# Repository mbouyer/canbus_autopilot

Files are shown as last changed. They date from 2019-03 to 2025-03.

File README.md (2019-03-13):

# canbus_autopilot
this is a canbus-connected marine autopilot, composed of 3 main parts:
* an IMU, implementing a MARG algorithm and transmitting attitude and rate of turn PGNs
* a display unit, allowing the user to display and change parameters of the autopilot
* a command unit, which is the autopilot itself. It drives the rudder's motor (in my case, and old Autohelm 2000 tiller).

These parts are built around a pic18f26j50, for its low power and native can support. The CAN protocol is based on J1939 and reuses NMEA2000 PGNs when possible.

There is also wxpilot, a wxwidget/socketcan utility which allows to show and change some of the autopilot's parameters from a unix computer (see my marine_charplotter repository)

The display unit can also decode and display navigation PGNs sent by my nmea2000_pi OpenCPN plugin.

I use this hardware for sailing since several years now

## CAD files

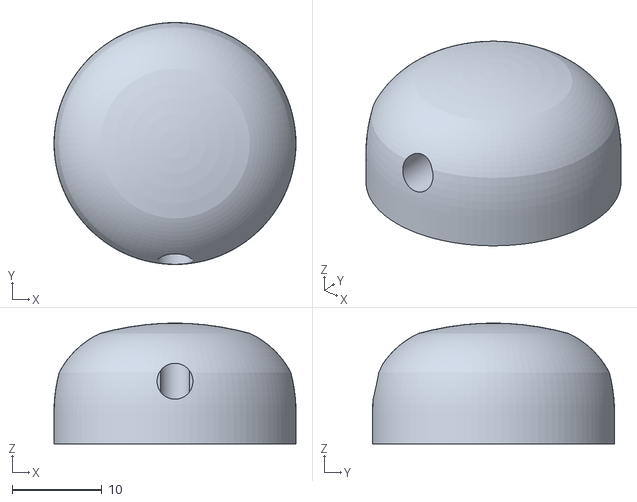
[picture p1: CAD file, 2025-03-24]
hardware/cad/bouton-3mm.stl
27.0 x 27.0 x 13.5

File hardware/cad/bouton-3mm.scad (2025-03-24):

$fa = 6;
$fs = 0.5;
$fn = 100;

difference() {
    rotate_extrude(angle = 360, convexity = 100) {
	import("bouton-3mm.dxf");
    };
    translate([0,0,7]) rotate([90,0,0]) cylinder(d=4, h=15);
}

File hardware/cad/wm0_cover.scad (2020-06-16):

$fn = 100;
// ABS: environ 1mm de retrait
// longueur_b = 4.10 * 25.4;
longueur_b = 113.8 + 0.9;
// largeur_b = 2.60 * 25.4;
largeur_b = 83.5 + 0.9;
hauteur_b = 60;
hauteur_b_droite = 7;
angle=4.9;
conge=4;
base_ep = 2;
murs_ep = 1.5;

hole_l = 22;
hole_x = 18;
hole_z = 24;

module hole() {
	translate([-murs_ep*2, 0, 0]) rotate([0,90,0]) union () {
		cylinder(d = hole_l, h=murs_ep * 4, $fn = 500);
		translate([0, -hole_l/2, 0]) cube([hole_z, hole_l, murs_ep * 4]);
	};
}

module coupe_conge(r) {
	translate([-(r - r * sin(angle)), -r, 0]) difference() {
		polygon(points = [
		    [0, 0],
		    [0, r],
		    [(r - r * sin(angle)), r],
		    [r, 0]
		    ]);
		circle(r = r, $fn = 500);
	};
}

module trapeze_conge(longueur, hauteur, r) {
	difference() {
	    polygon(points = [
		[-longueur/2, 0],
		[-(longueur/2 - hauteur * sin(angle)), hauteur],
		[(longueur/2 - hauteur * sin(angle)), hauteur],
		[longueur/2, 0]
		]);
	    translate([-(longueur/2 - hauteur * sin(angle)), hauteur, 0])
		rotate([0,180,0]) coupe_conge(r = r);
	    translate([(longueur/2 - hauteur * sin(angle)), hauteur, 0])
		coupe_conge(r = r);
	};
}

module pyramidal_1(longueur, largeur, hauteur, r) {
	rotate([90,0,0]) linear_extrude(height=largeur, center=true, convexity=10, twist=0)
	    trapeze_conge(longueur=longueur, hauteur=hauteur, r = r);
}

module pyramidal(longueur, largeur, hauteur, r) {
	intersection() {
		pyramidal_1(longueur, largeur, hauteur, r);
		rotate([0,0,90]) pyramidal_1(largeur, longueur, hauteur, r);
	}
}

module base(longueur, largeur, hauteur, r) {
	union() {
		translate([0,0,hauteur_b_droite / 2]) cube([longueur, largeur, hauteur_b_droite], center = true);
		translate([0,0,hauteur_b_droite]) pyramidal(longueur, largeur, hauteur_b - hauteur_b_droite, r);
	}
}
	

module box() {
	rotate([180,0,0]) difference() {
		translate([0,0,base_ep]) base(longueur_b+murs_ep*2, largeur_b+murs_ep*2, hauteur_b+base_ep, 0);
		base(longueur_b, largeur_b, hauteur_b, 4);
		translate([longueur_b/2, -largeur_b/2+hole_x, hole_z]) hole();
	};
}

box();

// difference() {
//  	box();
//  	translate([0,0,-hauteur_b / 2 - 20]) cube([longueur_b+10, largeur_b+10, hauteur_b], center=true);
// };
// hole();

// projection(cut=true) translate([0,0, -0.1]) box();

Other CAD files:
hardware/cad/bouton-3mm.dxf

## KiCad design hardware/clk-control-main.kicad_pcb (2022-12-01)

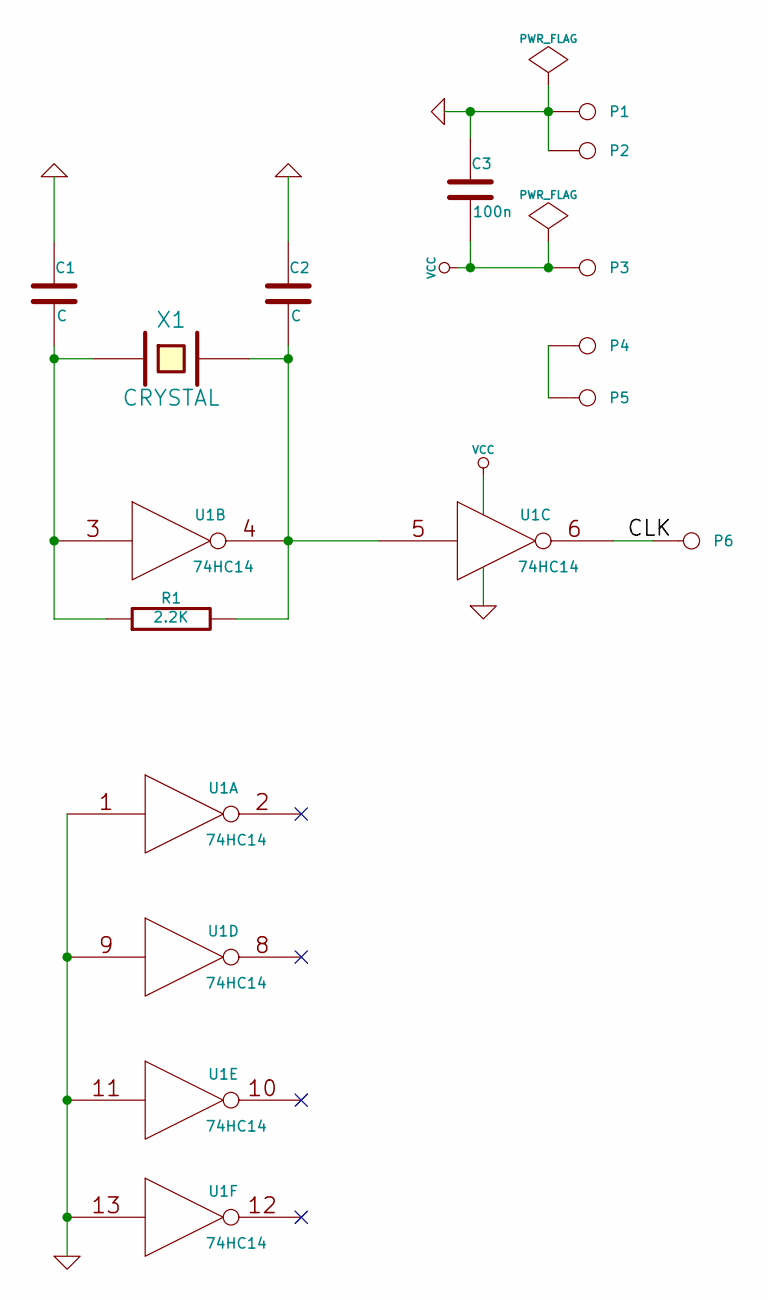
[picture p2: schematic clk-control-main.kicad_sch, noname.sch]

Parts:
C1, C2: C
C3: 100n
P1, P2, P3, P4, P5, P6: CONN_1
R1: 2.2K
U1: 74HC14
X1: CRYSTAL

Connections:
/CLK: P6.1, U1.6
GND: C1.1, C2.1, C3.1, P1.1, P2.1, U1.1, U1.7 (GND), U1.9, U1.11, U1.13
unnamed: P4.1, P5.1
unnamed: C2.2, R1.2, U1.4, U1.5, X1.2
unnamed: C1.2, R1.1, U1.3, X1.1
VCC: C3.2, P3.1, U1.14 (VCC)

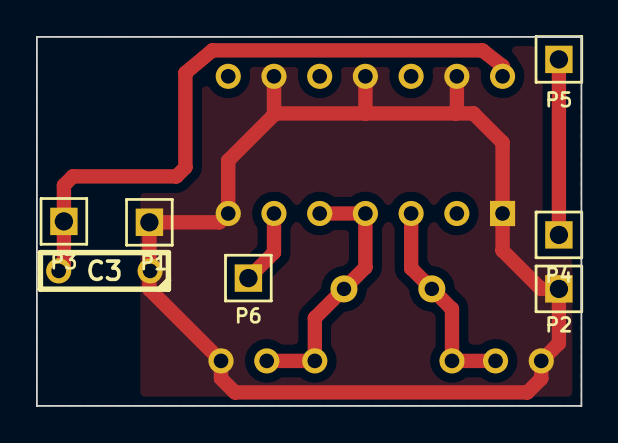
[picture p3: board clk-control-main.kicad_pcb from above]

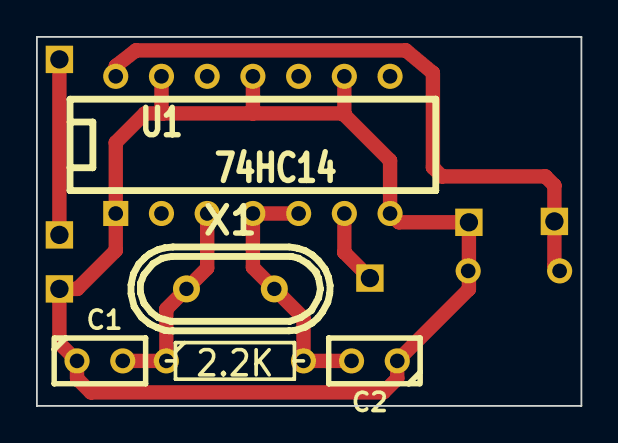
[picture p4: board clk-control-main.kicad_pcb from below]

Board: 2 copper layers, 30.2 x 20.5 mm, 12 parts (5 on the bottom side), 6 nets.

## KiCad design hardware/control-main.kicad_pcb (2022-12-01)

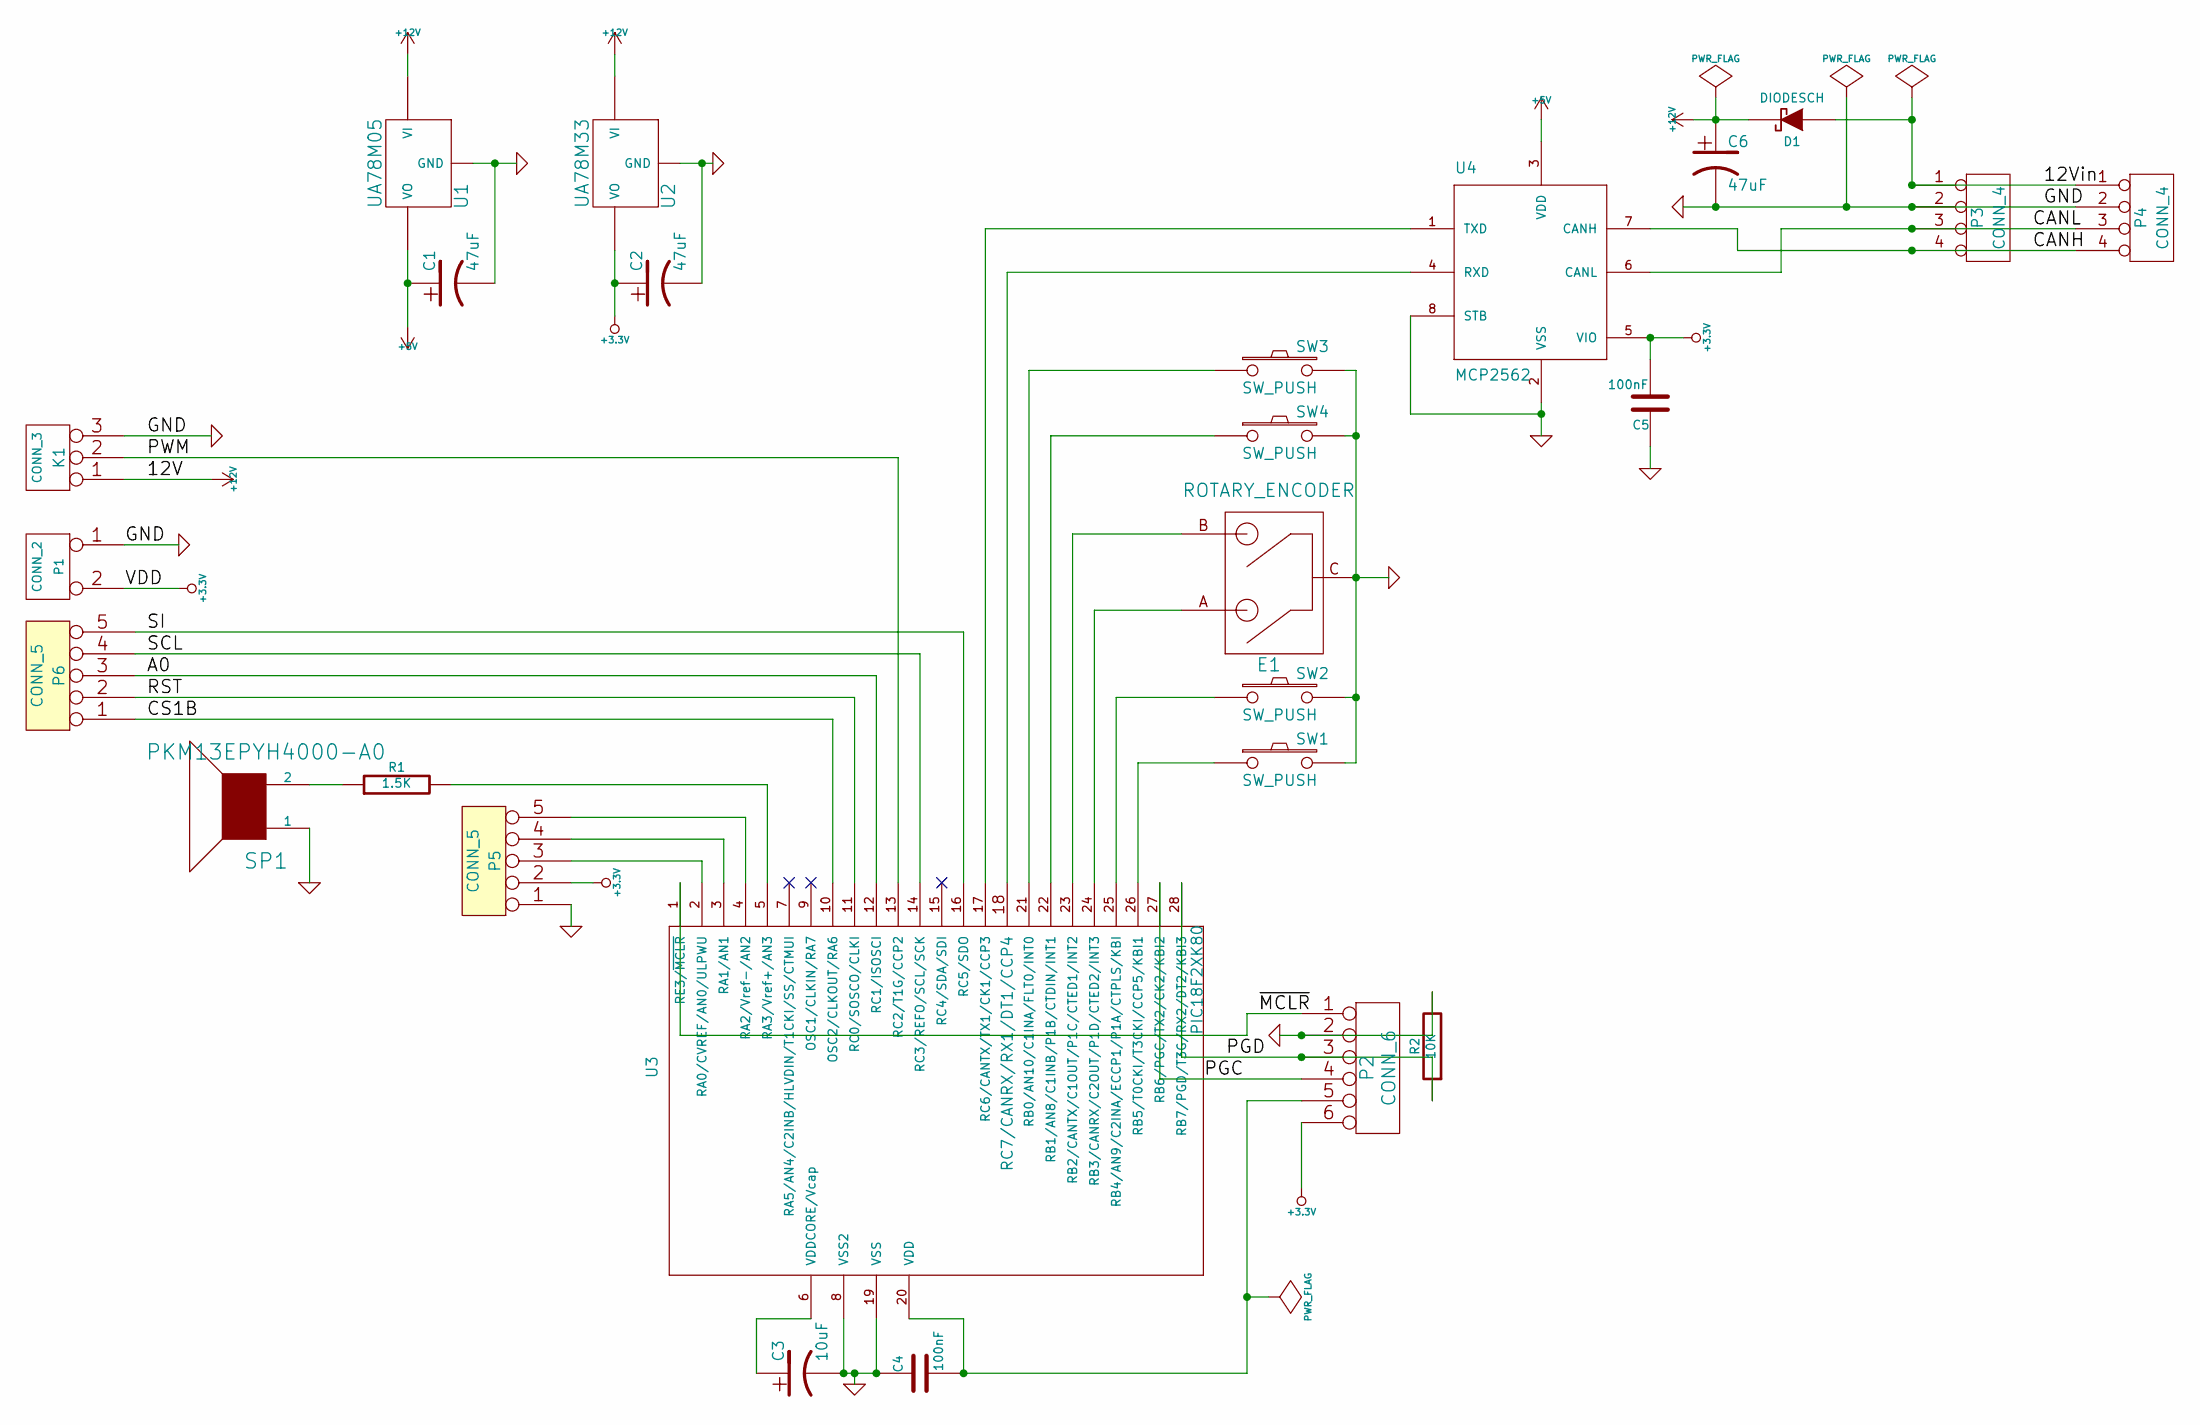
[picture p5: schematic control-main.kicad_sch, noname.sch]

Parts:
C1, C2, C6: 47uF
C3: 10uF
C4, C5: 100nF
D1: DIODESCH
E1: ROTARY_ENCODER
K1: CONN_3
P1: CONN_2
P2: CONN_6
P3, P4: CONN_4
P5, P6: CONN_5
R1: 1.5K
R2: 10K
SP1: PKM13EPYH4000-A0
SW1, SW2, SW3, SW4: SW_PUSH
U1: UA78M05
U2: UA78M33
U3: PIC18F2XK80
U4: MCP2562

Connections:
+3.3V: C2.1, C5.2, P1.2 (PM), P2.6, P5.2, U2.3 (VO), U4.5 (VIO)
+5V: C1.1, U1.3 (VO), U4.3 (VDD)
/A0: P6.3, U3.12 (RC1/ISOSCI)
/CANH: P3.4, P4.4, U4.7 (CANH)
/CANL: P3.3, P4.3, U4.6 (CANL)
/CS1B: P6.1, U3.10 (OSC2/CLKOUT/RA6)
/PGC: P2.4, U3.27 (RB6/PGC/TX2/CK2/KBI2)
/PGD: P2.3, R2.1, U3.28 (RB7/PGD/T3G/RX2/DT2/KBI3)
/PWM: K1.2 (PM), U3.13 (RC2/T1G/CCP2)
/RST: P6.2, U3.11 (RC0/SOSCO/CLKI)
/SCL: P6.4, U3.14 (RC3/REFO/SCL/SCK)
/SI: P6.5, U3.16 (RC5/SDO)
/~MCLR: P2.1, U3.1 (RE3/~MCLR)
unnamed: U3.17 (RC6/CANTX/TX1/CK1/CCP3), U4.1 (TXD)
unnamed: U3.18 (RC7/CANRX/RX1/DT1/CCP4), U4.4 (RXD)
unnamed: E1.B, U3.23 (RB2/CANTX/C1OUT/P1C/CTED1/INT2)
unnamed: C3.1, U3.6 (VDDCORE/Vcap)
unnamed: R1.2, U3.5 (RA3/Vref+/AN3)
unnamed: R1.1, SP1.2
unnamed: E1.A, U3.24 (RB3/CANRX/C2OUT/P1D/CTED2/INT3)
unnamed: SW3.1, U3.21 (RB0/AN10/C1INA/FLT0/INT0)
unnamed: P5.3, U3.2 (RA0/CVREF/AN0/ULPWU)
unnamed: SW2.1, U3.25 (RB4/AN9/C2INA/ECCP1/P1A/CTPLS/KBI)
unnamed: SW1.1, U3.26 (RB5/T0CKI/T3CKI/CCP5/KBI1)
unnamed: SW4.1, U3.22 (RB1/AN8/C1INB/P1B/CTDIN/INT1)
unnamed: P5.4, U3.3 (RA1/AN1)
unnamed: P5.5, U3.4 (RA2/Vref-/AN2)

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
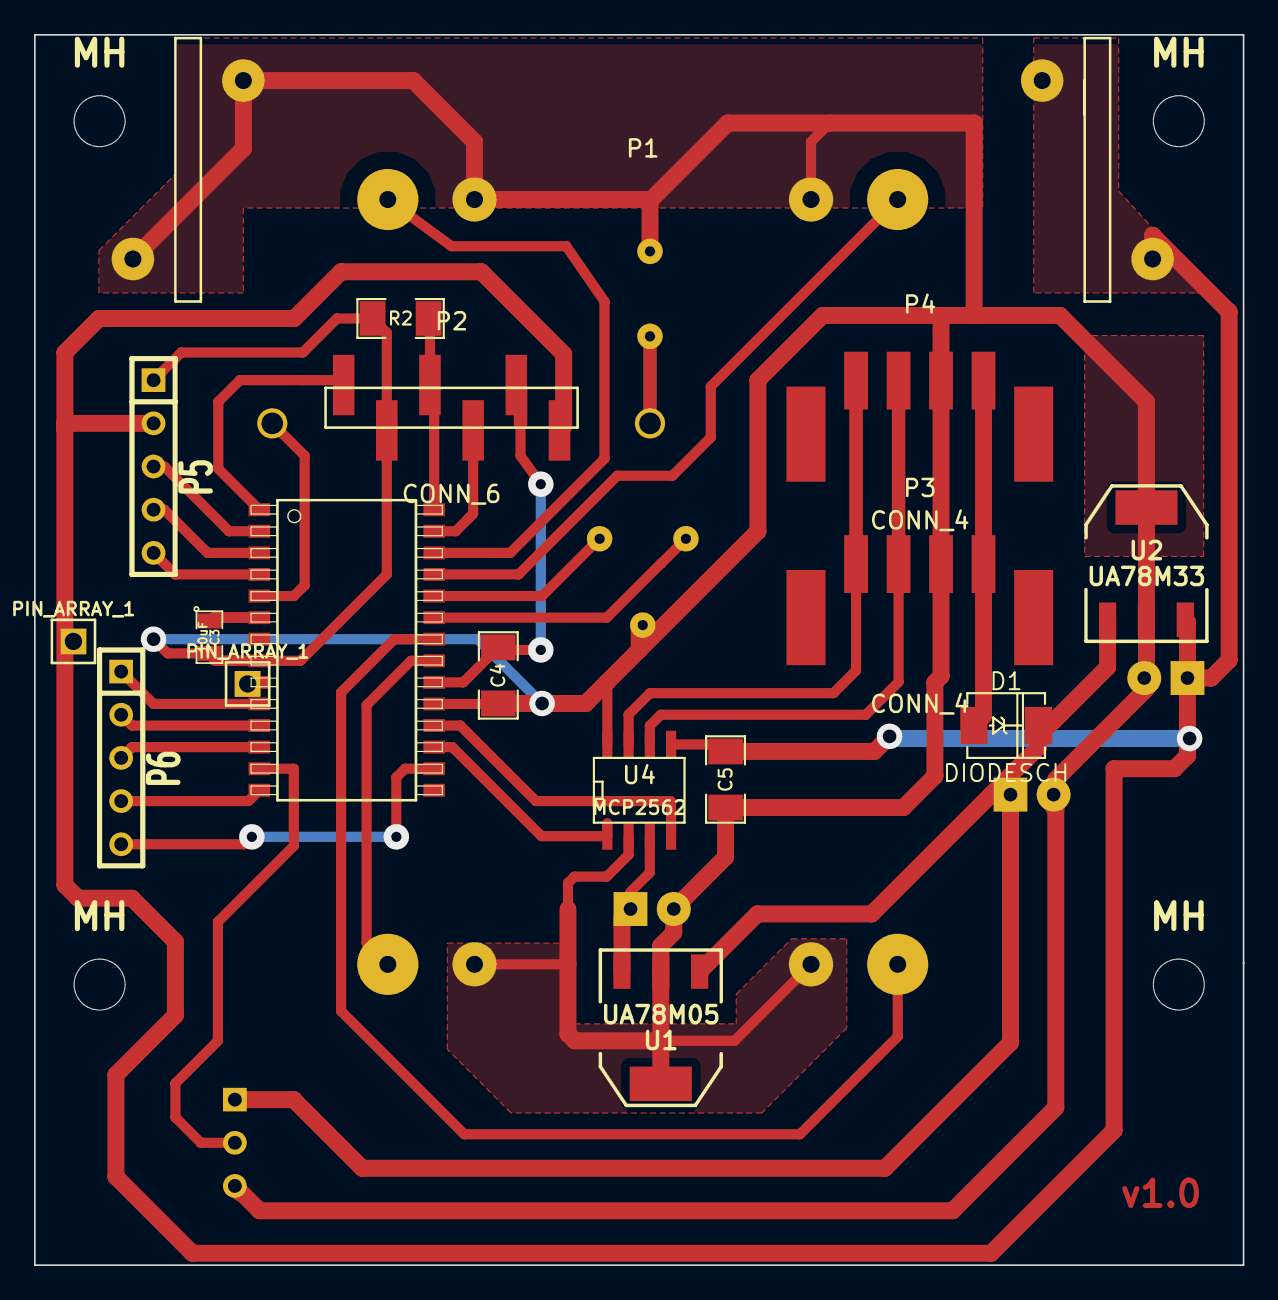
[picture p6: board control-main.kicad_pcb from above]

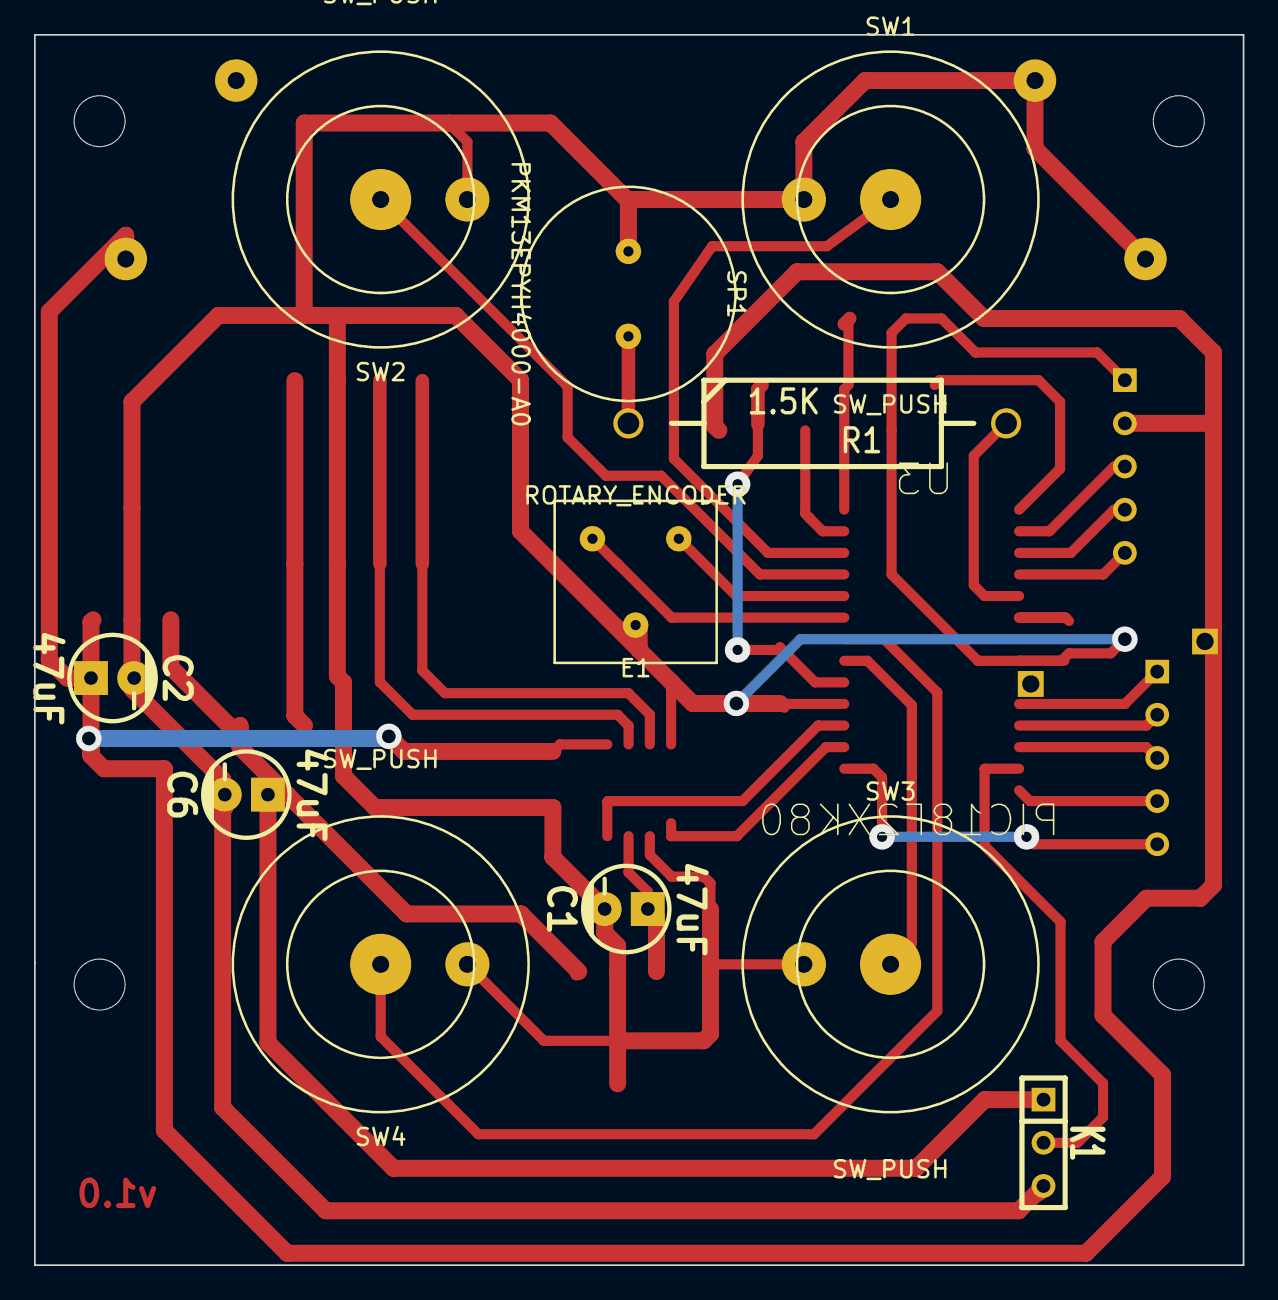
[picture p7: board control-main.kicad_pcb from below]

Board: 2 copper layers, 71.1 x 72.4 mm, 32 parts (11 on the bottom side), 31 nets.

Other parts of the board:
MH: MountingHole_3mm_RevA_Date21Jun2010
MH#2, MH#3, MH#4: MountingHole_3mm_RevA_Date21Jun2010
PIN_ARRAY_1, PIN_ARRAY_1#2: Val**; PIN_ARRAY_1

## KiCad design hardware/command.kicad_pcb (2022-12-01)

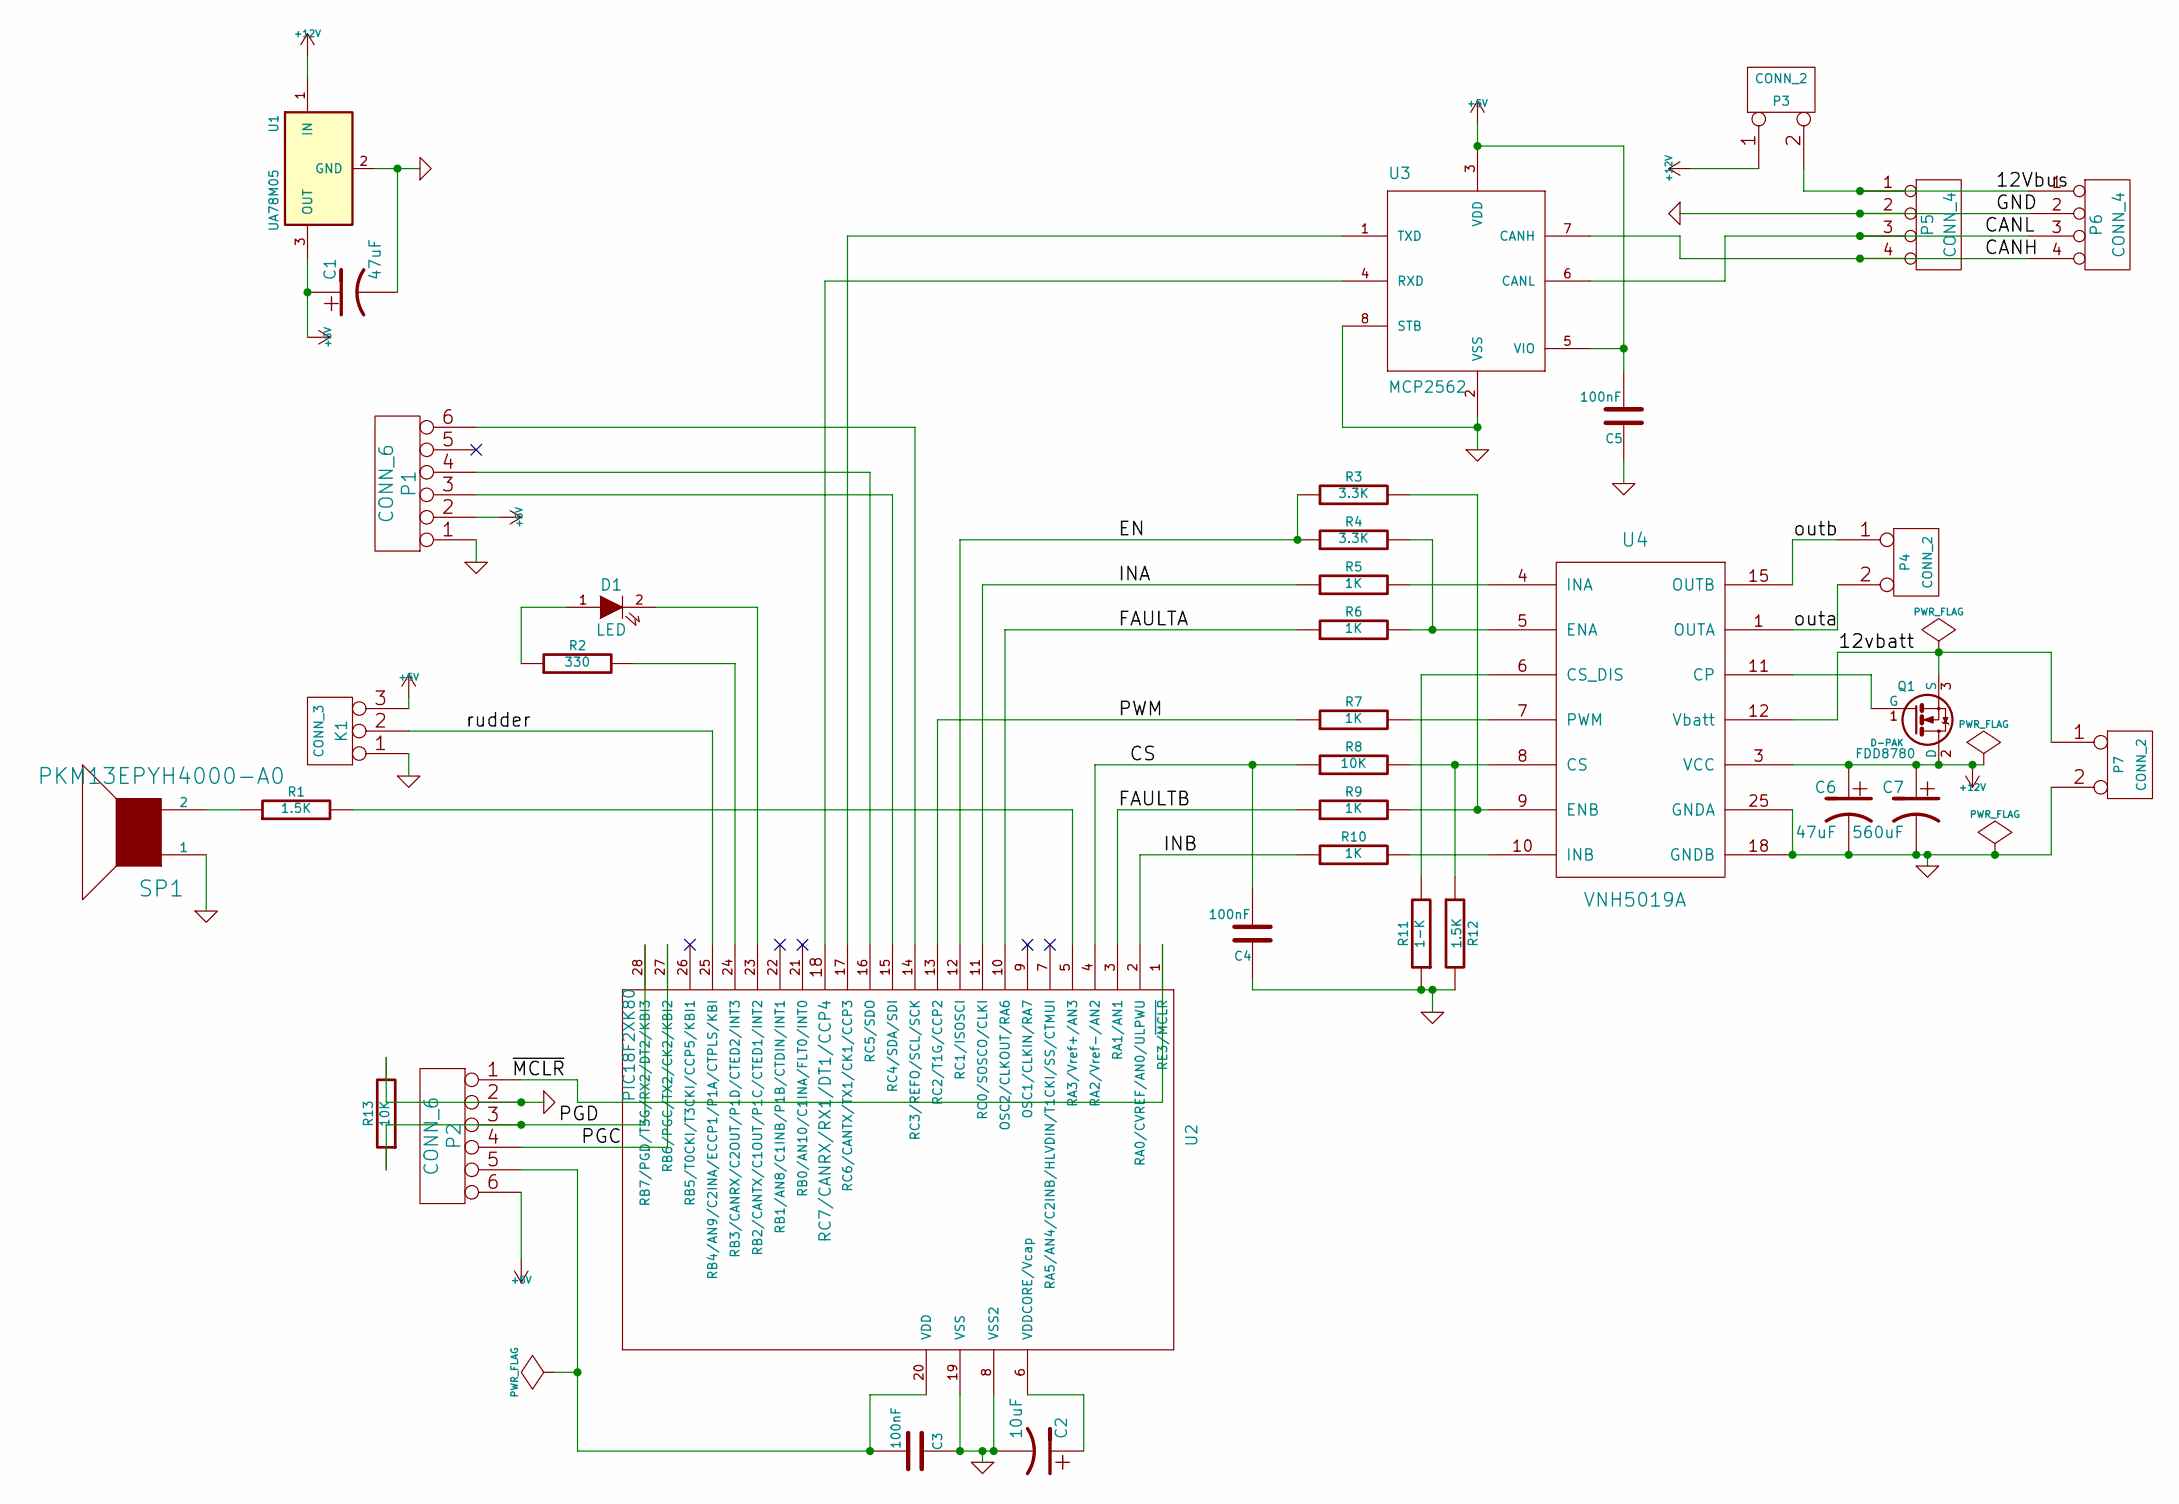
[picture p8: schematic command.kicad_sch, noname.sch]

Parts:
C1, C6: 47uF
C2: 10uF
C3, C4, C5: 100nF
C7: 560uF
D1: LED
K1: CONN_3
P1, P2: CONN_6
P3, P4, P7: CONN_2
P5, P6: CONN_4
Q1: FDD8780; D-PAK
R1, R12: 1.5K
R2: 330
R3, R4: 3.3K
R5, R6, R7, R9, R10: 1K
R8, R13: 10K
R11: 1-K
SP1: PKM13EPYH4000-A0
U1: UA78M05
U2: PIC18F2XK80
U3: MCP2562
U4: VNH5019A

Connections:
+5V: C1.1, C5.2, K1.3, P1.2, P2.6, U1.3 (OUT), U3.3 (VDD), U3.5 (VIO)
/12Vbus: P3.2 (PM), P5.1, P6.1
/CANH: P5.4, P6.4, U3.7 (CANH)
/CANL: P5.3, P6.3, U3.6 (CANL)
/CS: C4.2, R8.1, U2.4 (RA2/Vref-/AN2)
/EN: R3.1, R4.1, U2.12 (RC1/ISOSCI)
/FAULTA: R6.1, U2.10 (OSC2/CLKOUT/RA6)
/FAULTB: R9.1, U2.3 (RA1/AN1)
/INA: R5.1, U2.11 (RC0/SOSCO/CLKI)
/INB: R10.1, U2.2 (RA0/CVREF/AN0/ULPWU)
/PGC: P2.4, U2.27 (RB6/PGC/TX2/CK2/KBI2)
/PGD: P2.3, R13.1, U2.28 (RB7/PGD/T3G/RX2/DT2/KBI3)
/PWM: R7.1, U2.13 (RC2/T1G/CCP2)
/outa: P4.2 (PM), U4.1 (OUTA)
/outb: P4.1, U4.15 (OUTB)
/rudder: K1.2 (PM), U2.25 (RB4/AN9/C2INA/ECCP1/P1A/CTPLS/KBI)
/~MCLR: P2.1, U2.1 (RE3/~MCLR)
unnamed: C2.1, U2.6 (VDDCORE/Vcap)
unnamed: R1.2, U2.5 (RA3/Vref+/AN3)
unnamed: R1.1, SP1.2
unnamed: Q1.1 (G), U4.11 (CP)
unnamed: P1.3, U2.15 (RC4/SDA/SDI)
unnamed: P1.4, U2.16 (RC5/SDO)
unnamed: U2.18 (RC7/CANRX/RX1/DT1/CCP4), U3.4 (RXD)
unnamed: D1.2 (K), U2.23 (RB2/CANTX/C1OUT/P1C/CTED1/INT2)
unnamed: R2.2, U2.24 (RB3/CANRX/C2OUT/P1D/CTED2/INT3)
unnamed: P1.6, U2.14 (RC3/REFO/SCL/SCK)
unnamed: U2.17 (RC6/CANTX/TX1/CK1/CCP3), U3.1 (TXD)
unnamed: R11.2, U4.6 (CS_DIS)
unnamed: R10.2, U4.10 (INB)
unnamed: R8.2, R12.1, U4.8 (CS)
unnamed: R7.2, U4.7 (PWM)
unnamed: R5.2, U4.4 (INA)
unnamed: R3.2, R9.2, U4.9 (ENB)
unnamed: D1.1 (A), R2.1
unnamed: R4.2, R6.2, U4.5 (ENA)

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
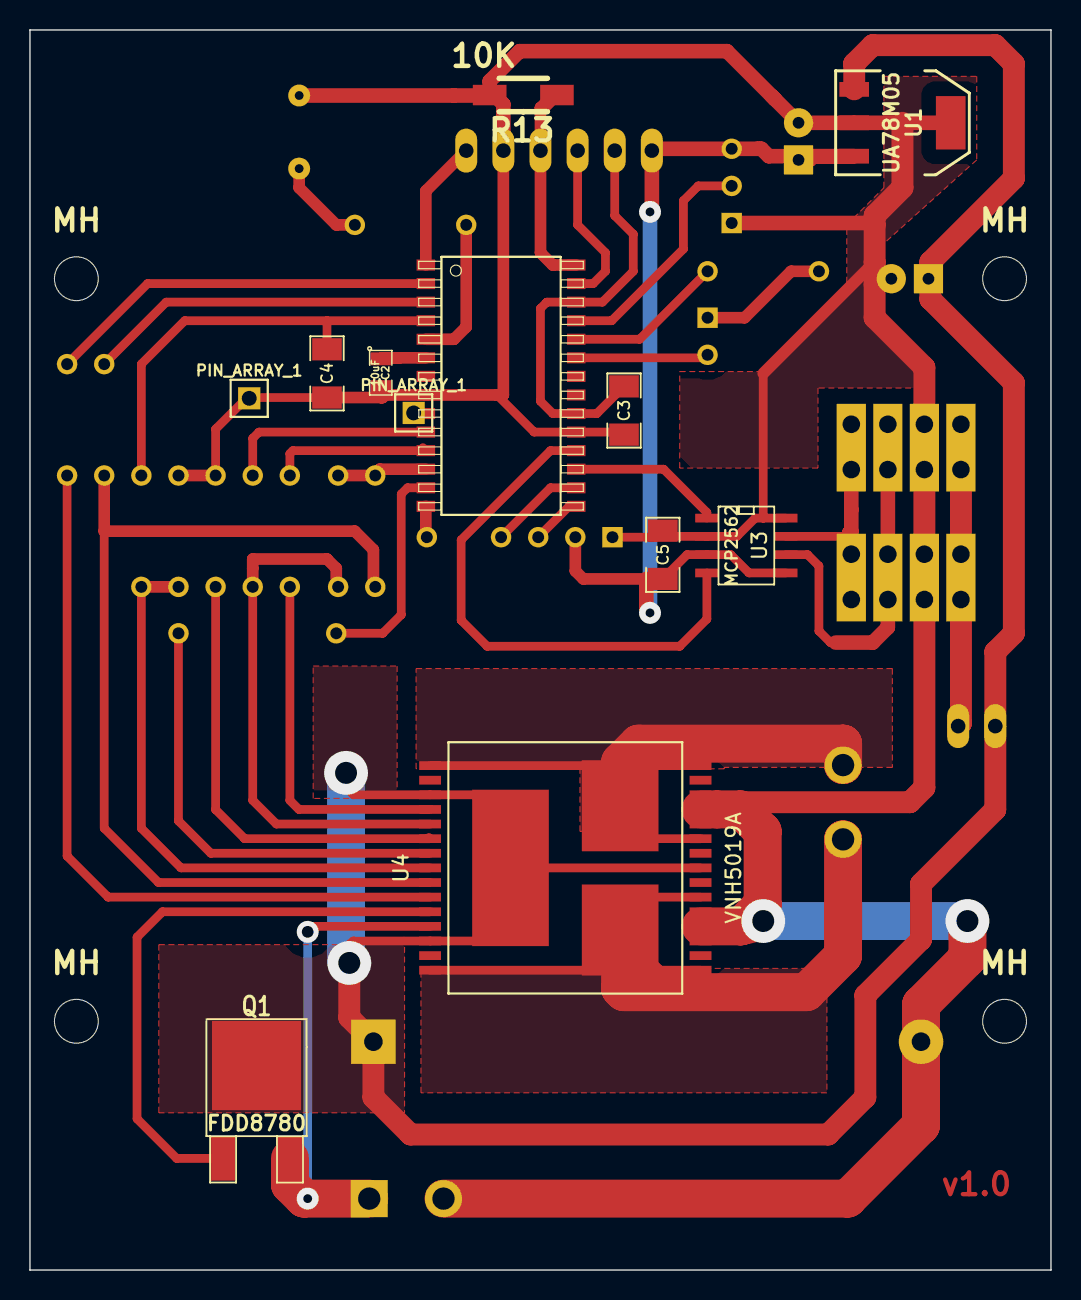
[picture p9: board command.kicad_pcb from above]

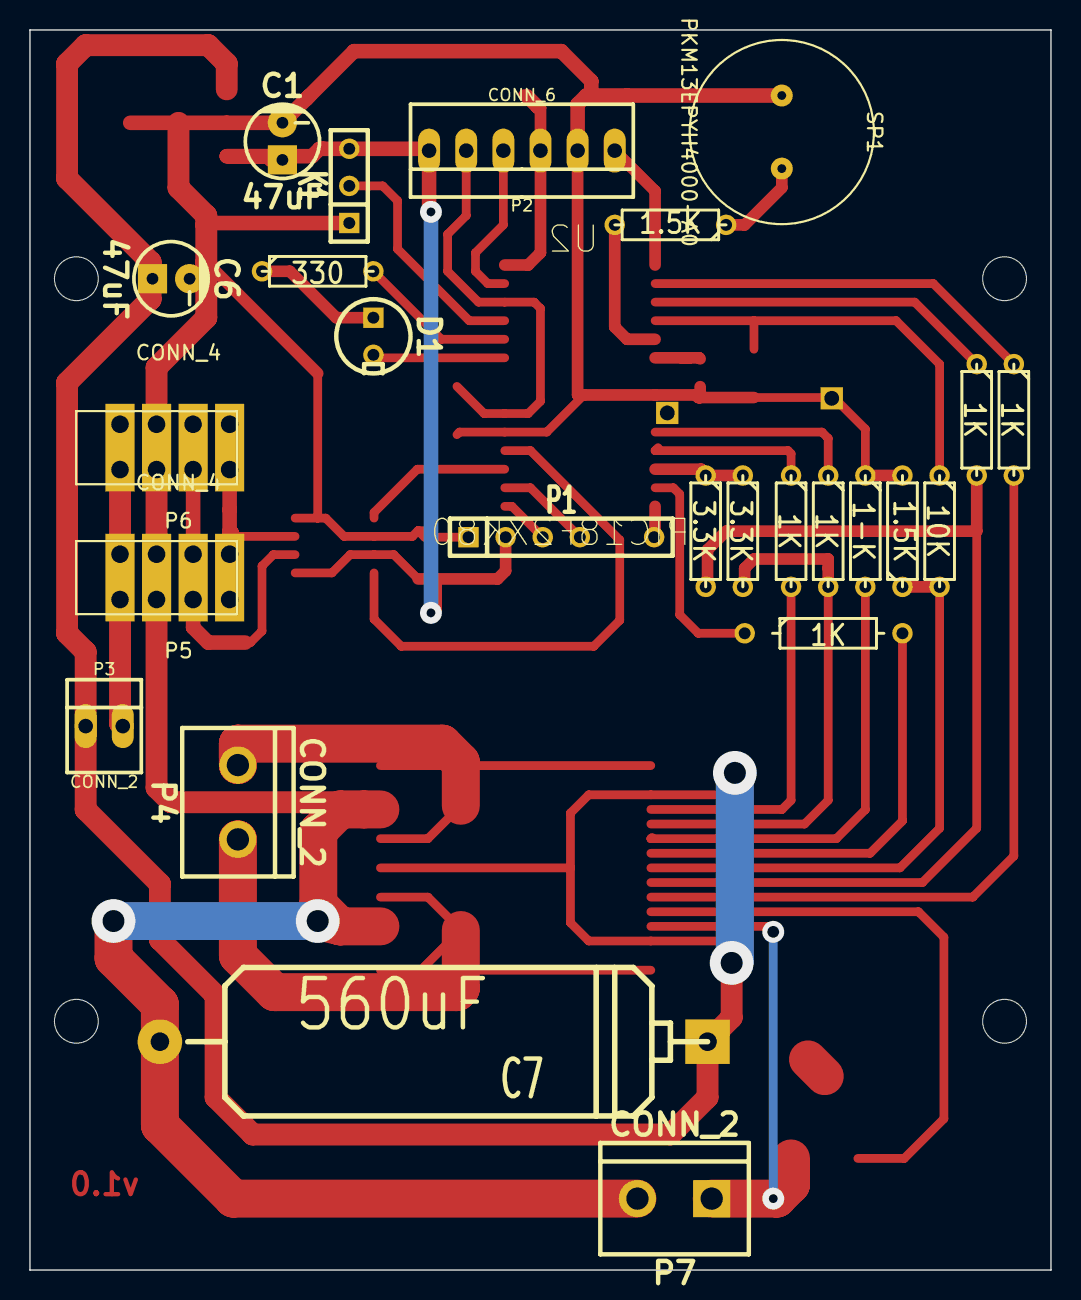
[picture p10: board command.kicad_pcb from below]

Board: 2 copper layers, 69.8 x 84.8 mm, 41 parts (25 on the bottom side), 40 nets.

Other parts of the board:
MH: MountingHole_3mm_RevA_Date21Jun2010
MH#2, MH#3, MH#4: MountingHole_3mm_RevA_Date21Jun2010
PIN_ARRAY_1, PIN_ARRAY_1#2: Val**; PIN_ARRAY_1

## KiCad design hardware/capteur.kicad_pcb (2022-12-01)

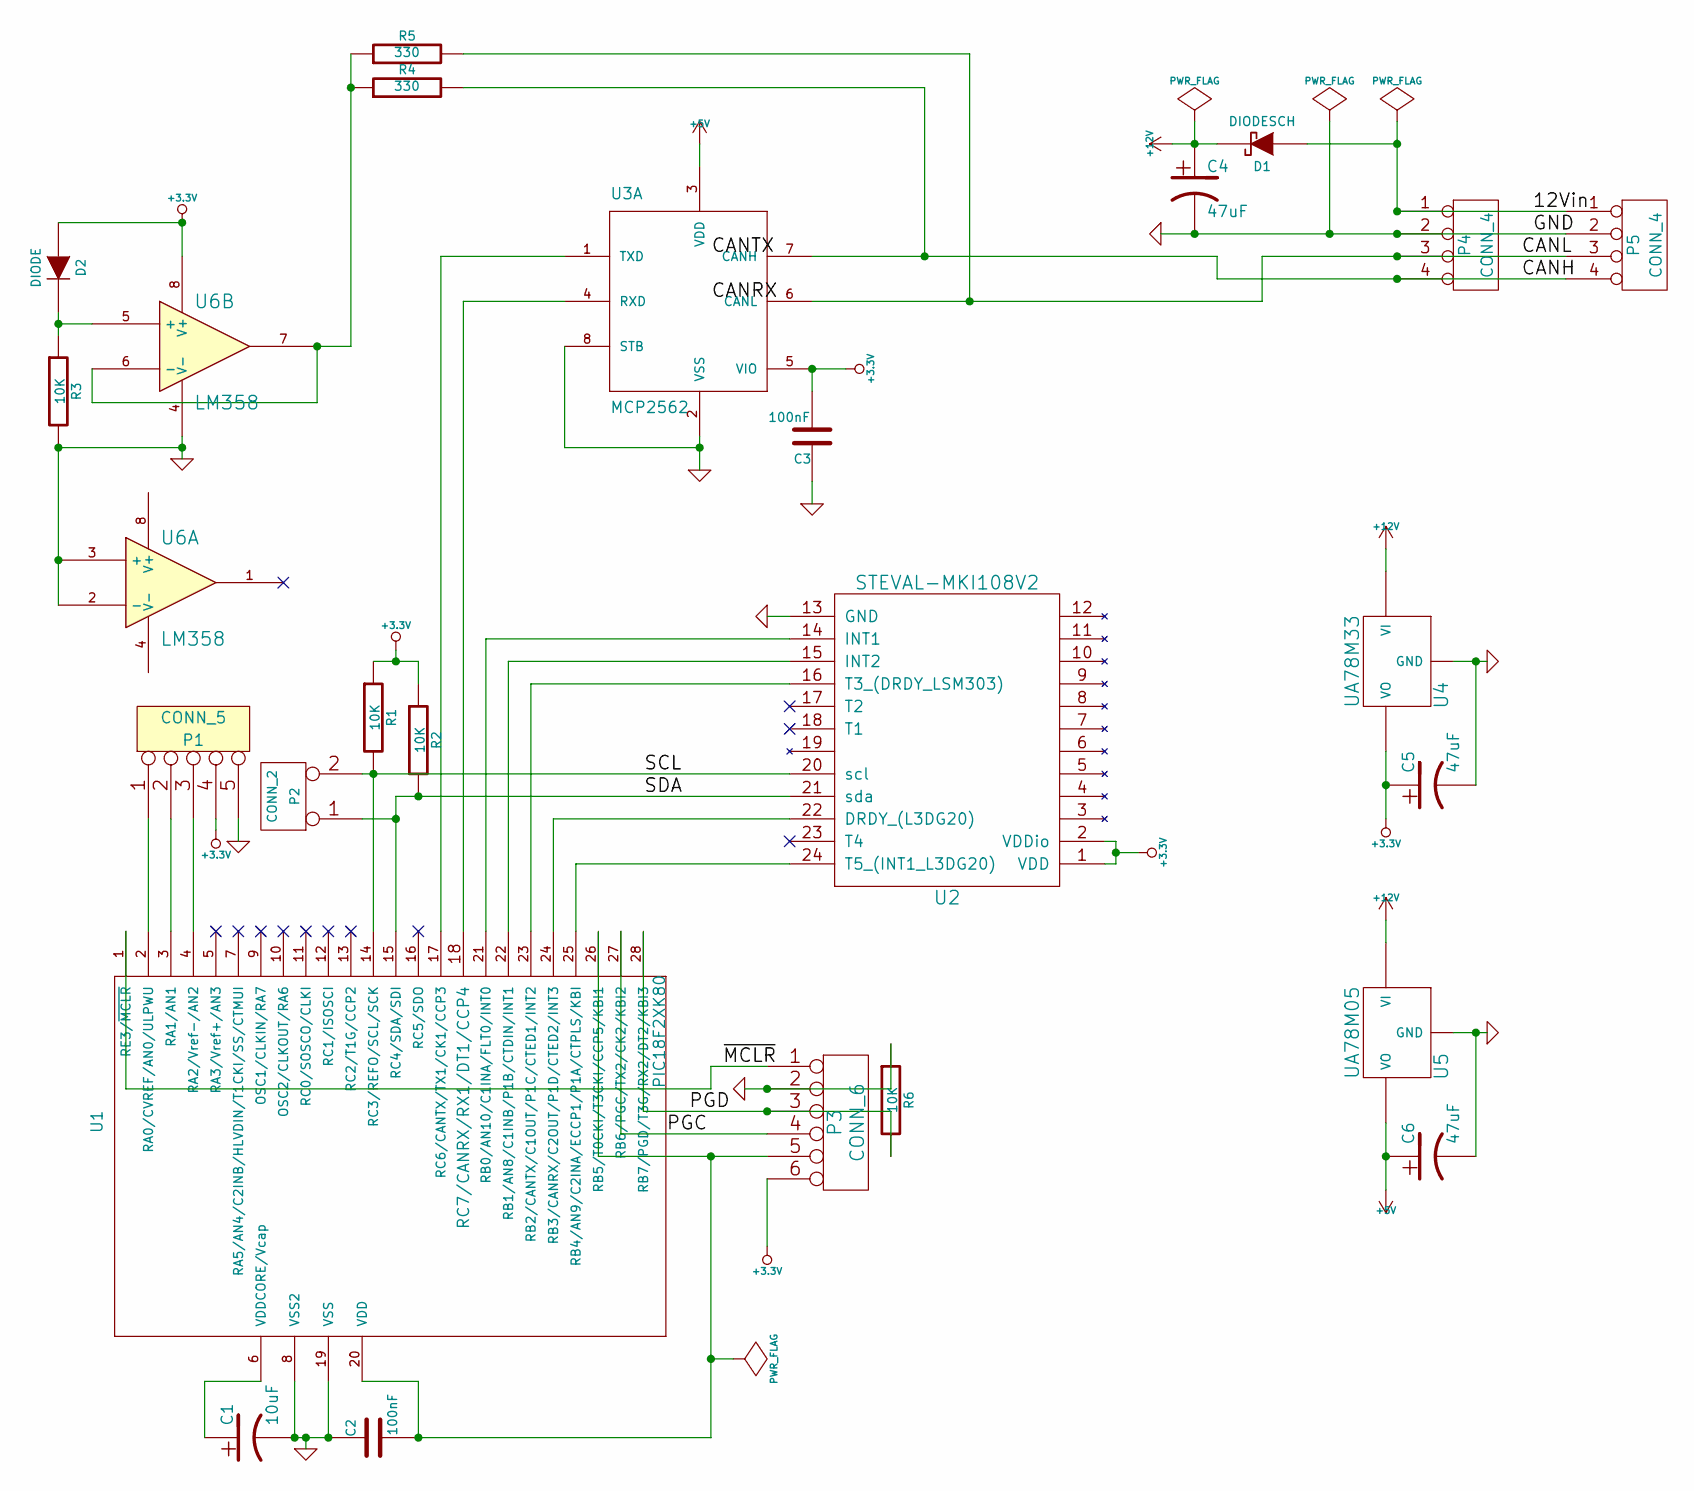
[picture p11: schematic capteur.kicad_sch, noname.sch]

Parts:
C1: 10uF
C2, C3: 100nF
C4, C5, C6: 47uF
D1: DIODESCH
D2: DIODE
P1: CONN_5
P2: CONN_2
P3: CONN_6
P4, P5: CONN_4
R1, R2, R3, R6: 10K
R4, R5: 330
U1: PIC18F2XK80
U2: STEVAL-MKI108V2
U3: MCP2562
U4: UA78M33
U5: UA78M05
U6: LM358

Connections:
+3.3V: C3.2, C5.1, D2.1 (A), P1.4, P3.6, R1.1, R2.1, U2.1 (VDD), U2.2 (VDDio), U3.5 (VIO), U4.3 (VO), U6.8 (V+)
+5V: C6.1, U3.3 (VDD), U5.3 (VO)
/CANH: P4.4, P5.4, R4.2, U3.7 (CANH)
/CANL: P4.3, P5.3, R5.2, U3.6 (CANL)
/PGC: P3.4, U1.27 (RB6/PGC/TX2/CK2/KBI2)
/PGD: P3.3, R6.2, U1.28 (RB7/PGD/T3G/RX2/DT2/KBI3)
/SCL: P2.2 (PM), R1.2, U1.14 (RC3/REFO/SCL/SCK), U2.20 (scl)
/SDA: P2.1, R2.2, U1.15 (RC4/SDA/SDI), U2.21 (sda)
/~MCLR: P3.1, U1.1 (RE3/~MCLR)
unnamed: C1.1, U1.6 (VDDCORE/Vcap)
unnamed: U1.17 (RC6/CANTX/TX1/CK1/CCP3), U3.1 (TXD)
unnamed: U1.18 (RC7/CANRX/RX1/DT1/CCP4), U3.4 (RXD)
unnamed: R4.1, R5.1, U6.6 (-), U6.7
unnamed: D2.2 (K), R3.1, U6.5 (+)
unnamed: U1.23 (RB2/CANTX/C1OUT/P1C/CTED1/INT2), U2.16 (T3_(DRDY_LSM303))
unnamed: U1.22 (RB1/AN8/C1INB/P1B/CTDIN/INT1), U2.15 (INT2)
unnamed: U1.21 (RB0/AN10/C1INA/FLT0/INT0), U2.14 (INT1)
unnamed: U1.25 (RB4/AN9/C2INA/ECCP1/P1A/CTPLS/KBI), U2.24 (T5_(INT1_L3DG20))
unnamed: U1.24 (RB3/CANRX/C2OUT/P1D/CTED2/INT3), U2.22 (DRDY_(L3DG20))
unnamed: P1.1, U1.2 (RA0/CVREF/AN0/ULPWU)
unnamed: P1.2, U1.3 (RA1/AN1)
unnamed: P1.3, U1.4 (RA2/Vref-/AN2)

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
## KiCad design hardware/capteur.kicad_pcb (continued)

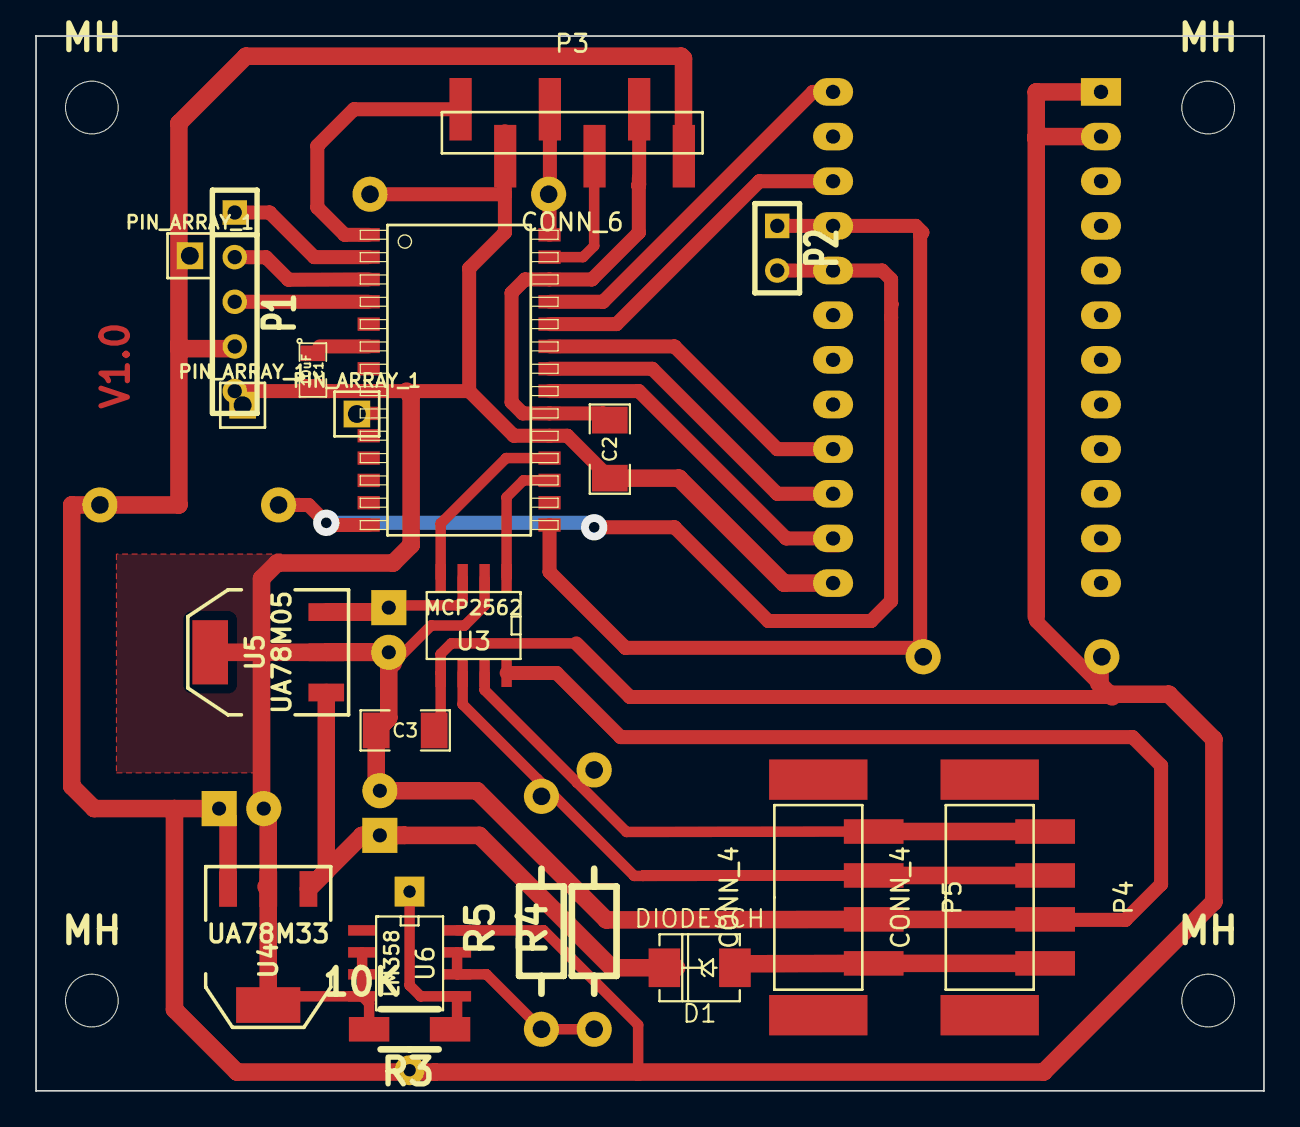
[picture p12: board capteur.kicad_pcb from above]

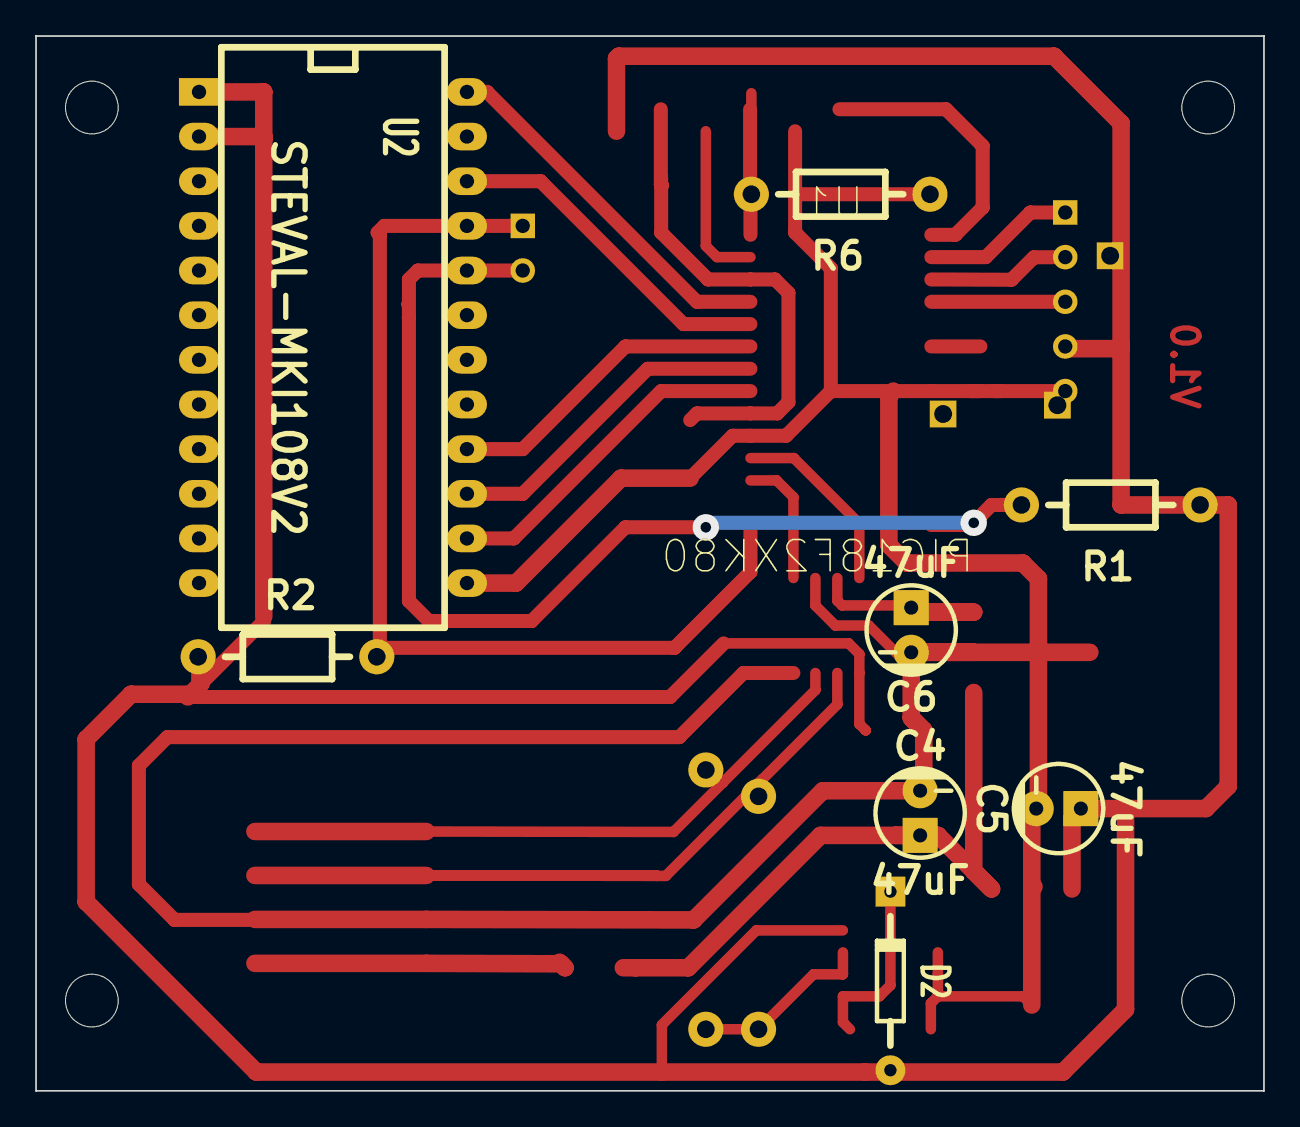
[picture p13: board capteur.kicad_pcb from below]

Board: 2 copper layers, 69.8 x 60.0 mm, 32 parts (8 on the bottom side), 26 nets.

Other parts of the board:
MH: MountingHole_3mm_RevA_Date21Jun2010
MH#2, MH#3, MH#4: MountingHole_3mm_RevA_Date21Jun2010
PIN_ARRAY_1, PIN_ARRAY_1#2, PIN_ARRAY_1#3: Val**; PIN_ARRAY_1

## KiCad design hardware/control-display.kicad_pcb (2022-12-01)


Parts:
C1, C2, C3, C4, C5, C6, C7, C8, C9, C10, C11, C12: 1uF
D1, D2: SL02
DISPLAY1: EADOGM132W5
IC1: LM3405
K1: CONN_3
L1: 68uH
P1: CONN_5
P2: CONN_2
R1: 5.1

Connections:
+3.3V: C1.1, DISPLAY1.34 (VDD2), DISPLAY1.35 (VDD), P2.2 (PM)
+12V: C12.1, IC1.5 (VIN), K1.1
DGND: C1.2, C2.1, C5.1, C6.1, C7.1, C8.1, C9.1, DISPLAY1.26 (VSS), DISPLAY1.33 (VSS2), P2.1
GNDPWR: C10.2, C12.2, D2.1 (A), IC1.2 (GND), K1.3, R1.2
unnamed: C10.1, D1.1 (A), DISPLAY1.20 (A2), L1.1
unnamed: DISPLAY1.2 (C1), IC1.3 (FB), R1.1
unnamed: C11.1, D1.2 (K), IC1.1 (BOOST)
unnamed: C11.2, D2.2 (K), IC1.6 (SW), L1.2
unnamed: DISPLAY1.1 (A1), DISPLAY1.19 (C2)
unnamed: IC1.4 (EN-DIM), K1.2 (PM)
unnamed: DISPLAY1.39 (RST), P1.2
unnamed: DISPLAY1.36 (SI), P1.5
unnamed: DISPLAY1.40 (CS1B), P1.1
unnamed: DISPLAY1.38 (A0), P1.3
unnamed: DISPLAY1.37 (SCL), P1.4
unnamed: C9.2, DISPLAY1.21 (V0)
unnamed: C8.2, DISPLAY1.22 (V1)
unnamed: C7.2, DISPLAY1.23 (V2)
unnamed: C6.2, DISPLAY1.24 (V3)
unnamed: C5.2, DISPLAY1.25 (V4)
unnamed: C3.1, DISPLAY1.30 (CAP1N)
unnamed: C2.2, DISPLAY1.31 (CAP3P), DISPLAY1.32 (VOUT)
unnamed: C4.2, DISPLAY1.27 (CAP2N)
unnamed: C4.1, DISPLAY1.28 (CAP2P)
unnamed: C3.2, DISPLAY1.29 (CAP1P)


Board: 2 copper layers, 55.0 x 33.0 mm, 21 parts (1 on the bottom side), 25 nets.

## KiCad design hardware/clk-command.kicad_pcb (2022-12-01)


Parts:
C1, C2: C
C3: 100n
P1, P2, P3, P4: CONN_1
R1: 4.7K
U1: 74HC14
X1: CRYSTAL

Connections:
/CLK: P4.1, U1.6
GND: C1.1, C2.1, C3.1, P1.1, U1.1, U1.7 (GND), U1.9, U1.11, U1.13
unnamed: C2.2, R1.2, U1.4, U1.5, X1.2
unnamed: C1.2, R1.1, U1.3, X1.1
VCC: C3.2, P2.1, P3.1, U1.14 (VCC)



Board: 2 copper layers, 31.0 x 34.0 mm, 10 parts (5 on the bottom side), 5 nets.

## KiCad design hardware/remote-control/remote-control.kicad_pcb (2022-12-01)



Board: 2 copper layers, 74.0 x 34.0 mm, 24 parts (9 on the bottom side), 21 nets.

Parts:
C1, C3: 22pF; C_Disc_D3.4mm_W2.1mm_P2.50mm
C2, C7, C8, C9: 10uF; C_0805_2012Metric_Pad1.15x1.40mm_HandSolder
C4, C5, C6: 100nF; C_0603_1608Metric_Pad1.05x0.95mm_HandSolder
D1: LED; LED_D3.0mm
D2: PMEG4005EGWX; D_SOD-123
J1: Conn_Coaxial; SMA_Molex_73251-2200_Horizontal
P1: CONN_6; PinHeader_1x06_P2.54mm_Vertical
P2, P3: CONN_4; TerminalBlock_Phoenix_PTSM-0,5-4-2.5-V-THR_1x04_P2.50mm_Ver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
R1: 330; R_0805_2012Metric_Pad1.15x1.40mm_HandSolder
R2: 10K; R_Axial_DIN0207_L6.3mm_D2.5mm_P7.62mm_Horizontal
TVS1: SMBJ16A; D_SMB_Handsoldering
U1: PIC18F2XK80; SOIC-28W_7.5x17.9mm_P1.27mm
U2: MCP2562; SOIC-8_3.9x4.9mm_P1.27mm
U3: ZPT; RFsolutions_ZPT-D
U4: UA78M33; SOT-223-3_TabPin2
U5: UA78M05; SOT-223-3_TabPin2
Y1: 10Mhz; Crystal_HC18-U_Vertical

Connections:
+3.3V: C5.2, C6.2, C8.1, D1.2, P1.5, U2.5, U3.4, U4.3
+5V: C9.1, U2.3, U5.3
+12V: C7.1, D2.1, U4.1, U5.1
/12Vin: D2.2, P2.1, P3.1, TVS1.1
/ANT: J1.1, U3.1
/CANN: P2.3, P3.3, U2.6
/CANP: P2.4, P3.4, U2.7
/CANRX: U1.24, U2.4
/CANTX: U1.23, U2.1
/PGC: P1.4, U1.27
/PGD: P1.3, R2.2, U1.28
/~MCLR: P1.1, U1.1
GND: C1.1, C2.2, C3.1, C4.1, C5.1, C6.1, C7.2, C8.2, C9.2, J1.2, P1.2, P2.2, P3.2, R2.1, TVS1.2, U1.8, U1.19, U2.2, U2.8, U3.2, U4.2, U5.2
unnamed: C1.2, U1.9, Y1.1
unnamed: C2.1, U1.6
unnamed: C3.2, U1.10, Y1.2
unnamed: C4.2, P1.6, U1.20, U1.26
unnamed: D1.1, R1.2
unnamed: R1.1, U3.5
unnamed: U1.17, U3.3
unnamed: U1.18, U3.6

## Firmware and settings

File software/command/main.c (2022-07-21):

/* $Id: main.c,v 1.20 2019/03/11 21:24:53 bouyer Exp $ */
/*
 * Copyright (c) 2017 Manuel Bouyer
 *
 * All rights reserved.
 *
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
 * THIS SOFTWARE IS PROVIDED BY THE NETBSD FOUNDATION, INC. AND CONTRIBUTORS
 * ``AS IS'' AND ANY EXPRESS OR IMPLIED WARRANTIES, INCLUDING, BUT NOT LIMITED
 * TO, THE IMPLIED WARRANTIES OF MERCHANTABILITY AND FITNESS FOR A PARTICULAR
 * PURPOSE ARE DISCLAIMED.  IN NO EVENT SHALL THE FOUNDATION OR CONTRIBUTORS
 * BE LIABLE FOR ANY DIRECT, INDIRECT, INCIDENTAL, SPECIAL, EXEMPLARY, OR
 * CONSEQUENTIAL DAMAGES (INCLUDING, BUT NOT LIMITED TO, PROCUREMENT OF
 * SUBSTITUTE GOODS OR SERVICES; LOSS OF USE, DATA, OR PROFITS; OR BUSINESS
 * INTERRUPTION) HOWEVER CAUSED AND ON ANY THEORY OF LIABILITY, WHETHER IN
 * CONTRACT, STRICT LIABILITY, OR TORT (INCLUDING NEGLIGENCE OR OTHERWISE)
 * ARISING IN ANY WAY OUT OF THE USE OF THIS SOFTWARE, EVEN IF ADVISED OF THE
 * POSSIBILITY OF SUCH DAMAGE.
 */

#include <pic18fregs.h>
#include <stdio.h>
#include <math.h>
#include <autopilot_serial.h>
#include <nmea2000.h>
#include <nmea2000_pgn.h>
#include <eeprom.h>
#include <raddeg.h>

extern char stack;
extern char stack_end;

#pragma stack 0x100 256

void _reset (void) __naked __interrupt 0;
void _startup (void) __naked;

unsigned long nmea2000_user_id;

static unsigned char sid;

static struct nmea2000_msg msg;
static unsigned char nmea2000_data[NMEA2000_DATA_LENGTH];

static int received_heading;
#define HEADING_INVALID 32767
static int received_pitch;
static int received_roll;
static int received_rot_rate;
static int previous_rot_rate;

unsigned int acuator_time;
unsigned int last_capteur_data;

unsigned int timer0_read(void);
#pragma callee_saves timer0_read

static char counter_10hz;
static char counter_1hz;
static volatile union softintrs {
	struct softintrs_bits {
		char int_10hz : 1;	/* 0.1s timer */
		char int_att  : 1;	/* got new attitude message */
		char int_rot  : 1;	/* got new rate of turn message */
		char int_ledo : 1;	/* toggle LED in timer intr handler */
	} bits;
	char byte;
} softintrs;

static int target_heading; /* heading to follow */
static int previous_target_heading;
static unsigned char auto_mode;

#define CLRWDT __asm__("clrwdt")

#define EN_ALL LATCbits.LATC1
#define EN_A   PORTAbits.RA6
#define EN_B   PORTAbits.RA1
#define IN_A   LATCbits.LATC0
#define IN_B   LATAbits.LATA0
#define PWM    LATCbits.LATC2

#define LEDR   LATBbits.LATB3
#define LEDG   LATBbits.LATB2

static unsigned char led_expire;
static unsigned char led_wait;

#define SPKR_PORT	LATAbits.LATA3
/* beep freq: 19.53125Khz / x */
#define SPKR_440        44 /* 440Hz */
#define SPKR_1000       19 /* 1Khz */
static unsigned char beep_duration;
#define SPKR_440_D100   88 /* 0.1s */
#define SPKR_1000_D100  200 /* 0.1s */

static union command_errors err_list, err_ack;

unsigned int a2d_motorcurrent; /* AN2 */
int a2d_rudder; /* AN9 */
int a2d_acc;
unsigned char a2d_idx;
unsigned char motor_overcurrent_count;
#define MOTORCURRENT_MAX 12000 // autohelm
// #define MOTORCURRENT_MAX 36000U // st2000+
#define MOTOR_OVERCURRENT_MAX 3 /* 0.3s */

#define RUDDER_MIN (3072 >> 4)
#define RUDDER_MAX (29736 >> 4)

#define RUDDER_MIN_TOL ((RUDDER_MIN) + (RUDDER_MAX - RUDDER_MIN) / 10)
#define RUDDER_MAX_TOL ((RUDDER_MAX) - (RUDDER_MAX - RUDDER_MIN) / 10)
static int rudder_min;
static int rudder_max;

/*
 * rudder PID parameters. half move (13330 / 16) = 833 in about 4s,
 * sample every 0.1s
 * so max speed is about +/-20 for an output of +/-125
 */
#define RUDDER_ERR_FACTOR   -100L
#define RUDDER_DIFF_FACTOR  -350L
#define RUDDER_INT_FACTOR  -1L
#define RUDDER_DIVIDE_FACTOR 64L

int rudder_cons;
int previous_rudder;
int previous_acuator_cmd;

/*
 * steering PID parameters. 
 * For output in R (inputs are in R, R/s and R.s * 10) (with R = rad * 10000)
 */
#define NPARAMS 6
struct steering_factors {
	int  factors[3];
} steering_factors[NPARAMS];

static char steering_factors_slot;

static float target_rudder;

static void
read_factors_from_eeprom(void)
{
	char *d = (void *)&steering_factors[0];
	char i, j;
	for (i = 0; i < sizeof(struct steering_factors) * NPARAMS; i++)
		d[i] = eeprom_read(i);
	for (i = 0; i < NPARAMS; i++) {
		for (j = 0; j < 3; j++) {
			if (steering_factors[i].factors[j] < 0 ||
			    steering_factors[i].factors[j] > 9999) {
				steering_factors[i].factors[j] = 0;
			}
		}
	}
}

static void
write_factors_to_eeprom(char slot) __wparam
{
	char *d = (void *)&steering_factors[slot];
	char i;
	for (i = 0; i < sizeof(struct steering_factors); i++)
		eeprom_write(i + slot * sizeof(struct steering_factors), d[i]);
}

static void
send_command_status(void)
{
	long rudder_report;
	struct private_command_status *data = (void *)&nmea2000_data[0];

	rudder_report = a2d_rudder - (RUDDER_MIN + RUDDER_MAX) / 2;
	rudder_report = rudder_report * 200 / (RUDDER_MAX - RUDDER_MIN);
	PGN2ID(PRIVATE_COMMAND_STATUS, msg.id);
	msg.id.priority = NMEA2000_PRIORITY_INFO;
	msg.dlc = sizeof(struct private_command_status);
	msg.data = &nmea2000_data[0];
	data->heading = target_heading;
	data->auto_mode = auto_mode;
	data->command_errors.byte = err_list.byte;
	data->rudder = rudder_report;
	data->params_slot = steering_factors_slot;
	if (! nmea2000_send_single_frame(&msg))
		printf("send PRIVATE_COMMAND_STATUS failed\n");
}

static void
send_command_factors(char addr, char slot)
{
	struct private_command_factors *data = (void *)&nmea2000_data[0];

	msg.id.id = 0;
	msg.id.priority = NMEA2000_PRIORITY_INFO;
	msg.id.iso_pg = (PRIVATE_COMMAND_FACTORS >> 8) & 0xff;
	msg.id.daddr = addr;
	msg.dlc = sizeof(struct private_command_factors);
	msg.data = &nmea2000_data[0];
	data->slot = slot;
	data->factors[0] = steering_factors[slot].factors[0];
	data->factors[1] = steering_factors[slot].factors[1];
	data->factors[2] = steering_factors[slot].factors[2];
	if (! nmea2000_send_single_frame(&msg))
		printf("send PRIVATE_COMMAND_FACTORS failed\n");
}

void
user_handle_iso_request(unsigned long pgn)
{
	printf("ISO_REQUEST for %ld from %d\n", pgn, rid.saddr);
	switch(pgn) {
	case PRIVATE_COMMAND_STATUS:
		send_command_status();
		break;
	}
}

void
user_receive()
{
	unsigned long pgn;
	unsigned char decoded=0;

	pgn = ((unsigned long)rid.page << 16) | ((unsigned long)rid.iso_pg << 8);
	if (rid.iso_pg > 239)
		pgn |= rid.daddr;

	switch(pgn) {
	case NMEA2000_ATTITUDE:
	{
		struct nmea2000_attitude_data *d = (void *)rdata;
		decoded = 1;
		received_heading = d->yaw;
		received_pitch = d->pitch;
		received_roll = d->roll;
		softintrs.bits.int_att = 1;
		break;
	}
	case NMEA2000_RATEOFTURN:
	{
		struct nmea2000_rateofturn_data *d = (void *)rdata;
		decoded = 1;
		if (d->rate > 32767000)
			received_rot_rate = 32767;
		else if (d->rate < -32767000)
			received_rot_rate = -32767;
		else
			received_rot_rate = d->rate / 1000;
		softintrs.bits.int_rot = 1;
		break;
	}
	case PRIVATE_COMMAND_ACUATOR:
		if (auto_mode & AUTO_STANDBY) {
			struct private_command_acuator *d = (void *)rdata;
			char move = d->move;
			decoded = 1;
#ifdef FAKE
			a2d_rudder = a2d_rudder + (move * 20);
			if (a2d_rudder < RUDDER_MIN)
				a2d_rudder = RUDDER_MIN;
			if (a2d_rudder > RUDDER_MAX)
				a2d_rudder = RUDDER_MAX;
#else
			if (move < 0) {
				IN_A = 1;
				IN_B = 0;
				move = -move;
			} else {
				IN_A = 0;
				IN_B = 1;
			}
			if (CCPR2L == 0)
				CCPR2L = 10;
			CCPR2L += 10 * move;
			CCP2CON = 0x0c; /* PWM on */
#endif
			acuator_time = timer0_read();

		}
		break;
	case PRIVATE_COMMAND_ENGAGE:
	{
		struct private_command_engage *d = (void *)rdata;
		char need_msg_update;
		if (target_heading != d->heading ||
		    auto_mode != d->auto_mode)
			need_msg_update = 1;
		else
			need_msg_update = 0;
		/* chech value */
		if (d->auto_mode == AUTO_OFF) {
			LEDR = LEDG = 0;
			softintrs.bits.int_ledo = 0;
			EN_ALL = 0;
			IN_A = 0;
			IN_B = 0;
			PWM = 0;
			CCPR2L = 0;
			CCP2CON = 0; /* PWM off */
			target_heading = HEADING_INVALID;
		} else if (d->auto_mode & AUTO_STANDBY) {
			LEDR = LEDG = 0;
			softintrs.bits.int_ledo = 0;
			EN_ALL = 1;
			IN_A = 0;
			IN_B = 0;
			PWM = 0;
			CCPR2L = 0;
			CCP2CON = 0; /* PWM off */
			target_heading = HEADING_INVALID;
		} else if (d->auto_mode & AUTO_HEAD) {
			if ((auto_mode & AUTO_HEAD) == 0) {
				LEDR = LEDG = 0;
				softintrs.bits.int_ledo = 0;
				auto_mode = AUTO_HEAD;
				/* init rudder pos */
				rudder_cons = previous_rudder =
				    a2d_rudder;
				target_rudder = rudder_cons;
				rudder_min = RUDDER_MIN;
				rudder_max = RUDDER_MAX;
				/* init PID */
				previous_rot_rate = received_rot_rate;
				/* power on but idle */
				EN_ALL = 1;
				IN_A = 0;
				IN_B = 0;
				PWM = 0;
				CCPR2L = 0;
				CCP2CON = 0; /* PWM off */
				/* init target move detection */
				previous_target_heading = received_heading;
			}
			target_heading = d->heading;
			steering_factors_slot = d->params_slot;
		}
		auto_mode = d->auto_mode;
		if (need_msg_update)
			send_command_status();
		decoded = 1;
		break;
	}
	case PRIVATE_COMMAND_ERRACK:
	{
		struct private_command_errack *d = (void *)rdata;
		decoded = 1;
		err_ack.byte = d->ack_errors.byte;
		err_list.byte &= ~d->ack_errors.byte;
		send_command_status();
		break;
	}
	case PRIVATE_COMMAND_FACTORS_REQUEST:
	{
		struct private_command_factors_request *d = (void *)rdata;
		decoded = 1;
		if (d->slot >= 0 && d->slot < NPARAMS) {
			send_command_factors(rid.saddr, d->slot);
		}
		break;
	}
	case PRIVATE_COMMAND_FACTORS:
	{
		struct private_command_factors *d = (void *)rdata;
		decoded = 1;
		printf("factors[%d]=%d %d %d\n", d->slot,
		    d->factors[0],
		    d->factors[1],
		    d->factors[2]);
		if (d->slot >= 0 && d->slot < NPARAMS) {
			steering_factors[d->slot].factors[0] =
			    d->factors[0];
			steering_factors[d->slot].factors[1] =
			    d->factors[1];
			steering_factors[d->slot].factors[2] =
			    d->factors[2];
			write_factors_to_eeprom(d->slot);
		}
		break;
	}
	}
#if 0
	if (decoded == 0) {
		unsigned char i;
		printf("got msg %6d %3d\n",
		   pgn, rid.saddr);
		printf("data:");
		for (i =0; i < 8; i++) {
			printf("%02x", rdata[i]);
		}
		putchar('\n');
	}
	else {
		printf("head %d pitch %d roll %d rate %d\n",
			received_heading,
			received_pitch,
			received_roll,
			received_rot_rate);
	}
#endif
}

/* compute needed acuator move */
static unsigned char
move_acuator(void)
{
#ifdef FAKE
	long rudder_error;

	rudder_error = rudder_cons - a2d_rudder;

	/* 5s for full to full, slow down for small moves */
	if (rudder_error < 10 && rudder_error >= -10)
		return 0;
	if (rudder_error > (RUDDER_MAX - RUDDER_MIN) / 50)
		rudder_error = (RUDDER_MAX - RUDDER_MIN) / 50;
	else
		rudder_error = rudder_error / 2;
	a2d_rudder += rudder_error;
	return 1;
#else
	long rudder_error;
	long rudder_speed;
	long acuator_cmd;
	int acuator_cmd_soft;

	rudder_error = rudder_cons - a2d_rudder;
	rudder_speed = previous_rudder - a2d_rudder;
	previous_rudder = a2d_rudder;

	if (rudder_error < 10 && rudder_error >= -10)
		return 0;
	acuator_cmd = (rudder_error * RUDDER_ERR_FACTOR) +
		      (rudder_speed * RUDDER_DIFF_FACTOR);
	acuator_cmd = acuator_cmd / RUDDER_DIVIDE_FACTOR;
	if ((acuator_cmd > 0 && previous_acuator_cmd < 0) ||
	    (acuator_cmd < 0 && previous_acuator_cmd > 0)) {
		/* fast invert; stop first */
		acuator_cmd = acuator_cmd_soft = 0;
	} else if ((acuator_cmd > 20 && acuator_cmd > previous_acuator_cmd) ||
		   (acuator_cmd < -20 && acuator_cmd < previous_acuator_cmd)) {
		/* we want to go faster */
		acuator_cmd_soft = (acuator_cmd + previous_acuator_cmd) / 2;
	} else {
		/* going slower; no need to be progressive */
		acuator_cmd_soft = acuator_cmd;
	}

	if (acuator_cmd_soft > 20) {
		IN_A = 0;
		IN_B = 1;
		LEDG = 1;
		LEDR = 0;
		softintrs.bits.int_ledo = 0;
		led_wait = 5;
		if (acuator_cmd_soft >= 125) {
			PWM = 1;
			CCP2CON = 0;
		} else {
			PWM = 0;
			CCPR2L = acuator_cmd_soft;
			CCP2CON = 0x0c;
		}
	} else if (acuator_cmd_soft < -20) {
		IN_A = 1;
		IN_B = 0;
		LEDG = 0;
		LEDR = 1;
		softintrs.bits.int_ledo = 0;
		led_wait = 5;
		if (acuator_cmd_soft <= -125) {
			PWM = 1;
			CCP2CON = 0;
		} else {
			PWM = 0;
			CCPR2L = -acuator_cmd_soft;
			CCP2CON = 0x0c;
		}
	} else {
		if (previous_acuator_cmd != 0) {
			if (led_expire == 0) {
				LEDG = 0;
				LEDR = 0;
			}
			IN_A = 0;
			IN_B = 0;
			PWM = 0;
			CCPR2L = 0;
			CCP2CON = 0;
		}
		acuator_cmd = 0;
	}
	previous_acuator_cmd = acuator_cmd;
	return 1;
#endif
}

static void
compute_rudder_cons(void)
{
	long heading_error, target_heading_move;
	float rudder_correct;
	int new_rudder_int;
	int d_rot;
	int target_rot;

	if (received_heading == HEADING_INVALID)
		return;

	target_rot = 0;
	if (previous_target_heading  != target_heading) {
		/* compute ROT of target */
		target_heading_move =
		    (long)previous_target_heading - (long)target_heading;
		if (target_heading_move > 31416L)
			target_heading_move = target_heading_move - 62832L;
		else if (target_heading_move < -31416L)
			target_heading_move = target_heading_move + 62832L;
		/* limit to 0.5rad/s */
		if (target_heading_move > 500)
			target_heading_move = 500;
		else if (target_heading_move < -500)
			target_heading_move = -500;
		/* account only for half in the final compute */
		target_rot = target_heading_move * 5; /* 10 / 2 */
		previous_target_heading -= target_heading_move;

		if (previous_target_heading > 31416L)
			previous_target_heading = previous_target_heading - 62832L;
		else if (previous_target_heading < -31416L)
			previous_target_heading = previous_target_heading + 62832L;
	}
	heading_error = (long)received_heading - (long)target_heading;

	if (heading_error >= 31416L)
		heading_error = heading_error - 62832L;
	else if (heading_error <= -31416L)
		heading_error = 62832L + heading_error;

	/* compute rotational acceleration */
	d_rot = (received_rot_rate - previous_rot_rate) * 10;
	previous_rot_rate = received_rot_rate;

	rudder_correct =
	  (float)heading_error *
	    (float)steering_factors[steering_factors_slot].factors[FACTOR_ERR] +
	  ((float)received_rot_rate + (float)target_rot) *
	    (float)steering_factors[steering_factors_slot].factors[FACTOR_DIF] +
	  (float)d_rot *
	    (float)steering_factors[steering_factors_slot].factors[FACTOR_DIF2];
	/*
	 * we have to divide rudder_correct by 100000 because the
	 * factors are * 100000. 
	 * then convert to rudder unit. RUDDER_MAX - RUDDER_MIN is
	 * about 60 deg, or 1047 millirads */
	/* convert back to deg */
#if 0
	rudder_correct = (rudder_correct / 100000 *
			(float)((RUDDER_MAX - RUDDER_MIN) / 1047 ));
#endif
	rudder_correct = (rudder_correct * 0.000000009551098 *
	    (float)((RUDDER_MAX - RUDDER_MIN)));

	target_rudder += rudder_correct;
	if (target_rudder < rudder_min)
		target_rudder = rudder_min;
	else if (target_rudder > rudder_max)
		target_rudder = rudder_max;
	new_rudder_int = target_rudder;

	/* try to avoid unneeded small moves */
	if (new_rudder_int - rudder_cons > 0 || 
	    new_rudder_int - rudder_cons < -0) {
		rudder_cons = new_rudder_int;
	}
}

void
main(void) __naked
{
	unsigned char c;
	static unsigned int poll_count;
	static unsigned char acuator_temp_off;
	unsigned int count;
	static unsigned int conv_count;
	static unsigned char motor_overcurrent_count;

	sid = 0;

	softintrs.byte = 0;
	counter_10hz = 100;
	counter_1hz = 10;

	auto_mode = AUTO_OFF;
	target_heading = HEADING_INVALID;
	led_wait = 5;
	received_heading = HEADING_INVALID;

	/* everything is low priority by default */
	IPR1 = 0;
	IPR2 = 0;
	IPR3 = 0;
	IPR4 = 0;
	IPR5 = 0;
	INTCON = 0;
	INTCON2 = 0;
	INTCON3 = 0;

	RCONbits.IPEN=1; /* enable interrupt priority */

	/* configure timer0 as free-running counter at 9.765625Khz */
	T0CON = 0x07; /* b00000111: internal clock, 1/256 prescaler */
	INTCONbits.TMR0IF = 0;
	INTCONbits.TMR0IE = 0; /* no interrupt */
	T0CONbits.TMR0ON = 1;

	/* configure timer2 for 1Khz interrupt */
	PMD1bits.TMR2MD=0;
	T2CON = 0x21; /* b00100001: postscaller 1/5, prescaler 1/4 */
	PR2 = 125; /* 1khz output */
	T2CONbits.TMR2ON = 1;
	PIR1bits.TMR2IF = 0;
	IPR1bits.TMR2IP = 1; /* high priority interrupt */
	PIE1bits.TMR2IE = 1;

	/* prepare timer4 for speaker drive */
	PMD1bits.TMR4MD=0;
	T4CON = 0x2f; /* b00101111: postscaller 1/16, prescaler 1/4 */
	PR4 = 255; /* 150Hz by default */
	beep_duration = 0;
	T4CONbits.TMR4ON = 0; /* keep off for now */
	PIR4bits.TMR4IF = 0;
	IPR4bits.TMR4IP = 1; /* high priority interrupt */
	PIE4bits.TMR4IE = 1;

	USART_INIT(0);

	INTCONbits.GIE_GIEH=1;  /* enable high-priority interrupts */
	INTCONbits.PEIE_GIEL=1; /* enable low-priority interrrupts */

	/* read user-id from config bits */
	nmea2000_user_id = 0;
	__asm
	movlw UPPER __IDLOC0
	movwf _TBLPTRU, a
	movlw HIGH __IDLOC0
	movwf _TBLPTRH, a
	movlw LOW __IDLOC0
	movwf _TBLPTRL, a
	tblrd*+;
	movff _TABLAT, _nmea2000_user_id;
	tblrd*+;
	movff _TABLAT, _nmea2000_user_id + 1;
	__endasm;

	nmea2000_init();

	/* configure inputs/outputs */
	ANCON0 = 0xfd;
	ANCON1 = 0xff;
	/* shutdown power module */
	EN_ALL = 0;
	TRISCbits.TRISC1 = 0;
	/* shutdown PWM output */
	PWM = 0;
	TRISCbits.TRISC2 = 0;
	/* direction inputs to 0 */
	IN_A = 0;
	IN_B = 0;
	TRISCbits.TRISC0 = 0;
	TRISAbits.TRISA0 = 0;

	/* prepare pwm2: use timer2 */
	CCPTMRSbits.C2TSEL = 0;

	/* spkr off */
	SPKR_PORT = 0;
	TRISAbits.TRISA3 = 0;

	/* LED on, red */
	LEDR = 1;
	LEDG = 0;
	TRISBbits.TRISB2 = 0;
	TRISBbits.TRISB3 = 0;

	stdout = STREAM_USER; /* Use the macro PUTCHAR with printf */

	printf("Hello world\n");

#ifndef FAKE
	/* set up ADC */
	PIR1bits.ADIF = 0;
	ADCON0 = (2 << 2); /* select channel 2 */
	ADCON1 = 0x00;
	ADCON2 = 0xbd; /* Right justified, 20Tad Aq, Fosc/16 */
	ADCON0bits.ADON = 1;
	ADCON0bits.GO = 1; /* start */
#endif
	a2d_acc = 0;
	a2d_idx = 8;

	/* enable watch dog timer */
	WDTCON = 0x01;

	printf("ready");
	poll_count = timer0_read();
	while (nmea2000_status != NMEA2000_S_OK) {
		nmea2000_poll(5);
		while ((timer0_read() - poll_count) < 48) {
			nmea2000_receive();
		}
		poll_count = timer0_read();
		CLRWDT;
	}

	LEDR = 0;
	LEDG = 1;
	printf(", addr %d, id %ld\n", nmea2000_addr, nmea2000_user_id);
	PR4 = SPKR_440;
	T4CONbits.TMR4ON = 1;
	count = timer0_read();
	while (timer0_read() - count < 10000)
		; // wait
	T4CONbits.TMR4ON = 0;
	SPKR_PORT = 0;
	LEDG = 0;
	conv_count = 0;
	motor_overcurrent_count = 0;
	a2d_rudder = (RUDDER_MIN + RUDDER_MAX) / 2;
	a2d_motorcurrent = 0;
	err_list.byte = err_ack.byte = 0;

	previous_acuator_cmd = 0;
	read_factors_from_eeprom();

#if 0
	steering_factors[0].factors[0] = 1000;
	steering_factors[0].factors[1] = 2000;
	steering_factors[0].factors[2] = 10;
#endif
	steering_factors_slot = 0;

again:
	while (1) {
		CLRWDT;
		if (PIR1bits.ADIF) {
			PIR1bits.ADIF = 0;
			a2d_acc += ((unsigned int)ADRESH << 8) | ADRESL;
			a2d_idx--;
			if (a2d_idx == 0) {
				ADCON0bits.ADON = 0;
				if ((ADCON0 & 0x7c) == (2 << 2)) {
					/* we got motor current */
					a2d_motorcurrent = a2d_acc;
					/* switch to rudder */
					ADCON0 = (9 << 2);
					ADCON1 = 0x00;
				} else {
					/* we got rudder */
					a2d_rudder = a2d_acc >> 4;
					/* switch to motor */
					ADCON0 = (2 << 2);
					ADCON1 = 0x20;
					conv_count++;
				}
				ADCON0bits.ADON = 1;
				a2d_acc = 0;
				a2d_idx = 8;
			}
			ADCON0bits.GO = 1; /* start */
		}

		if ((auto_mode & AUTO_STANDBY) != 0 &&
		    (timer0_read() - acuator_time) > 2000) {
			IN_A = 0;
			IN_B = 0;
			CCPR2L = 0;
			CCP2CON = 0; /* PWM off */
		}

		if (softintrs.bits.int_10hz) {
			unsigned char needs_status_update = 0;
			softintrs.bits.int_10hz = 0;
			if (led_expire > 0) {
				led_expire--;
				if (led_expire == 0) {
					LEDR = LEDG = 0;
					softintrs.bits.int_ledo = 0;
				}
			}
#ifndef FAKE
			if (acuator_temp_off > 0) {
				acuator_temp_off--;
				if (acuator_temp_off == 0) {
					EN_ALL = 1;
					err_list.bits.output_overload = 0;
					err_ack.bits.output_overload = 0;
				}
			}
			if (a2d_motorcurrent > MOTORCURRENT_MAX) {
				motor_overcurrent_count++;
				if (motor_overcurrent_count >=
				    MOTOR_OVERCURRENT_MAX) {
					printf("E %d", a2d_motorcurrent);
					EN_ALL = 0;
					acuator_temp_off = 10;
					if (a2d_rudder > RUDDER_MAX_TOL) {
						rudder_max = a2d_rudder;
					} else if (a2d_rudder < RUDDER_MIN_TOL){
						rudder_min = a2d_rudder;
					} else if (
					    !err_list.bits.output_overload &&
					    !err_ack.bits.output_overload) {
						err_list.bits.output_overload = 1;
					}
				}
			} else {
				motor_overcurrent_count = 0;
			}
			if (EN_ALL && (EN_A == 0 || EN_B == 0)) {
				if (!err_list.bits.output_error &&
				    !err_ack.bits.output_error) {
					err_list.bits.output_error = 1;
				}
			} else {
				err_list.bits.output_error = 0;
				err_ack.bits.output_error = 0;
			}
			if (a2d_rudder < RUDDER_MIN - 30 ||
			    a2d_rudder > RUDDER_MAX + 30) {
				if (!err_list.bits.no_rudder_data &&
				    !err_ack.bits.no_rudder_data) {
					err_list.bits.no_rudder_data = 1;
				}
			} else {
				err_list.bits.no_rudder_data = 0;
				err_ack.bits.no_rudder_data = 0;
			}
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

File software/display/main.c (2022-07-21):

/* $Id: main.c,v 1.36 2019/03/12 19:24:19 bouyer Exp $ */
/*
 * Copyright (c) 2017 Manuel Bouyer
 *
 * All rights reserved.
 *
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
 * THIS SOFTWARE IS PROVIDED BY THE NETBSD FOUNDATION, INC. AND CONTRIBUTORS
 * ``AS IS'' AND ANY EXPRESS OR IMPLIED WARRANTIES, INCLUDING, BUT NOT LIMITED
 * TO, THE IMPLIED WARRANTIES OF MERCHANTABILITY AND FITNESS FOR A PARTICULAR
 * PURPOSE ARE DISCLAIMED.  IN NO EVENT SHALL THE FOUNDATION OR CONTRIBUTORS
 * BE LIABLE FOR ANY DIRECT, INDIRECT, INCIDENTAL, SPECIAL, EXEMPLARY, OR
 * CONSEQUENTIAL DAMAGES (INCLUDING, BUT NOT LIMITED TO, PROCUREMENT OF
 * SUBSTITUTE GOODS OR SERVICES; LOSS OF USE, DATA, OR PROFITS; OR BUSINESS
 * INTERRUPTION) HOWEVER CAUSED AND ON ANY THEORY OF LIABILITY, WHETHER IN
 * CONTRACT, STRICT LIABILITY, OR TORT (INCLUDING NEGLIGENCE OR OTHERWISE)
 * ARISING IN ANY WAY OUT OF THE USE OF THIS SOFTWARE, EVEN IF ADVISED OF THE
 * POSSIBILITY OF SUCH DAMAGE.
 */

#include <pic18fregs.h>
#include <stdio.h> 
#include <string.h> 
#include <stdlib.h> 
#include <math.h> 
#include <autopilot_serial.h> 
#include <autopilot_spi.h> 
#include <nmea2000.h> 
#include <nmea2000_pgn.h> 
#include <eeprom.h> 
#include <raddeg.h> 
#include <font5x8.h> 
#include <font10x16.h> 
#define USE_2024
#ifdef USE_2024
#include <font20x24.h> 
#endif
#include <menu.h> 

extern unsigned char stack; 
extern unsigned char stack_end;

#pragma stack 0x100 256

void _reset (void) __naked __interrupt 0;
void _startup (void) __naked;

unsigned long nmea2000_user_id; 

unsigned short timer0_read(void);
void delay(unsigned short);
#pragma callee_saves timer0_read

/* hardware defines */
#define BACK_PORT	LATCbits.LATC2

#define SPKR_PORT	LATAbits.LATA3

#define ROTARY_A	PORTBbits.RB3
#define ROTARY_B	PORTBbits.RB2

#define SW1		(!PORTBbits.RB5)
#define SW2		(!PORTBbits.RB4)
#define SW3		(!PORTBbits.RB0)
#define SW4		(!PORTBbits.RB1)

/* beep freq: 19.53125Khz / x */
#define SPKR_440	44 /* 440Hz */
#define SPKR_1000	19 /* 1Khz */
static unsigned char beep_duration;
#define SPKR_440_D100	88 /* 0.1s */
#define SPKR_1000_D100	200 /* 0.1s */

/* LCD-relayted defines (hardware and protocol) */
#define A0 LATCbits.LATC1
#define A0_CTRL 0
#define A0_DISP 1
#define PAGE_ADDR(c) ((unsigned char)0xb0 | c)
#define COL_ADDR_H(c) ((unsigned char)0x10 | (c >> 4))
#define COL_ADDR_L(c) ((unsigned char)0x00 | (c & 0x0f))

/* various global variables */
unsigned char lcd_ready;

static struct nmea2000_msg msg;
static unsigned char nmea2000_data[NMEA2000_DATA_LENGTH];

union {
	struct nmea2000_navdata_data s;
	unsigned char d[sizeof(struct nmea2000_navdata_data)];
} nmea2000_navdata_data;
unsigned char nmea2000_navdata_id;
unsigned char nmea2000_navdata_len;

static unsigned int received_heading;
#define HEADING_INVALID 32767
static int received_pitch;
static int received_roll;
static long received_rot_rate;
static int received_compass_offset;

static unsigned int received_cog; /* also use HEADING_INVALID */
static unsigned char received_speed;
static unsigned char received_speedd;
static unsigned char cogsog_changed;
unsigned short last_nmea2000_cogsog;

static long received_xte; /* in m * 100 */
#define XTE_INVALID 0
static unsigned char xte_changed;
unsigned short last_nmea2000_xte;

static unsigned int received_towp_cog; /* also use HEADING_INVALID */
static unsigned long received_towp_dist; /* in m  * 100 */
static unsigned long received_towp_idx; /* dest. waypoint index */
static          char received_towp_speed;
static unsigned char received_towp_speedd;
static unsigned char towp_changed;
static unsigned long previous_towp_idx;
static unsigned char new_wp;
unsigned short last_nmea2000_navdata;

unsigned char nmea2000_capteur_address;
unsigned short last_capteur_data;
unsigned char nmea2000_command_address;
unsigned short last_command_data;

unsigned char received_hours;
#define HOUR_INVALID 0xff
int received_minutes;
unsigned char datetime_changed;
unsigned short last_datetime_data;

static union command_errors cmderr_list;
int command_received_heading;
unsigned char received_auto_mode;
char received_rudder;
char received_param_slot;
int command_target_heading;
struct private_command_factors command_factors;

static volatile unsigned short counter_1hz;
static volatile unsigned int softintrs;
#define INT_1HZ		0x0001
#define INT_SW_R	0x0002
#define INT_SW_1P	0x0004 /* key press */
#define INT_SW_2P	0x0008
#define INT_SW_3P	0x0010
#define INT_SW_4P	0x0020
#define INT_SW_1R	0x0040 /* key release */
#define INT_SW_2R	0x0080
#define INT_SW_3R	0x0100
#define INT_SW_4R	0x0200

union inputs_status {
	struct {
		unsigned rotary_a	: 1;
		unsigned rotary_b	: 1;
		unsigned pending_a	: 1;
		unsigned pending_b	: 1;
		unsigned sw1		: 1;
		unsigned sw2		: 1;
		unsigned sw3		: 1;
		unsigned sw4		: 1;
	} s;
	unsigned char v;
};

static union inputs_status inputs_status;
static volatile char rotary_pos;
static char saved_rotary_pos;
static unsigned char rotary_a;
static unsigned char rotary_b;
static unsigned char sw1;
static unsigned char sw2;
static unsigned char sw3;
static unsigned char sw4;
union switch_events {
	struct {
		unsigned sw1	: 1; /* short press */
		unsigned sw2	: 1;
		unsigned sw3	: 1;
		unsigned sw4	: 1;
		unsigned sw1l	: 1; /* long press */
		unsigned sw2l	: 1;
		unsigned sw3l	: 1;
		unsigned sw4l	: 1;
	} s;
	char v;
};
static union switch_events switch_events;

static void get_rotary_pos(void) 
{
		INTCONbits.GIE_GIEH=0;
		saved_rotary_pos = rotary_pos;
		rotary_pos = 0;
		softintrs &= ~INT_SW_R;
		INTCONbits.GIE_GIEH=1;
}
#define CLRWDT __asm__("clrwdt")

unsigned char backlight_pr;
#define BACKLIGHT_ADDR 0x00 /* address of backlight_pr save in eeprom */
unsigned char backlight_status;
static unsigned char lcd_col;
static unsigned char lcd_line;
#define DISPLAY_W	132
#define DISPLAY_H	4
char lcd_displaybuf[DISPLAY_W / 6];
#define DISPLAY_FONTSMALL_W	6
#define DISPLAY_FONTMEDIUM_W	10
#define DISPLAY_FONTLARGE_W	20
static void displaybuf_small(void);
static void displaybuf_medium(void);
static void displaybuf_large(void);
static void resetdisplay(void);
static void cleardisplay(void);
static void clearline(unsigned char) __wparam;
enum display_page display_page;
enum display_page previous_display_page;
enum display_page next_display_page;
unsigned short last_display_update;

static char page_displaymenu(const struct page_menu_entry *, char, char);

static void page_mainmenu(char) __wparam;
static void page_confmenu(char) __wparam;
static void page_maindata(char) __wparam;
static void page_light(char) __wparam;
static void page_charlist(char) __wparam;
static void page_rawdata_capt(char) __wparam;
static void page_rawdata_cmd(char) __wparam;
static void page_err(char) __wparam;
static void page_cmderr(char) __wparam;
static void page_edisplay(char) __wparam;

static union displar_errs {
    struct {
	char nocapt	: 1;
	char nocmd	: 1;
    } bits;
    unsigned char byte;
} err_list, err_ack;
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

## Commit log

2019-03-13 Initial move of the autopilot electronic design to github
    [capteur.kicad_pcb, capteur.sch, clk-capteur.kicad_pcb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]
2019-03-14 As we compute relative rudder moves, which accumulate over time, we can consider the PID as being against the rate of turn instead of heading. The target of the PID is a ROT of 0, with the heading er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
    [main.c]
2019-03-15 Use defines instead of hard-coded numbers for param slots
2019-03-17 Add a MUTE control message, which ask a device to stop sending user frames (only bus control is still handled). Add a socketcan tool to mute/unmute an address.
2019-03-17 Switch to use static reserved memory, avoids saving registers and multiple banksel. Saves about 15ms per round, or more than 16%.
2019-03-17 Move several variables from int to short; as sizeof(int) moved from 2 to 4.
    [main.c]
2019-03-24 move timer0_read() from int to short, as now int == long handle rotary_pos in an interrupt_safe way Change timer2 from 1Khz to 500hz, for the benefit of PWM (one more bit) and key debounce Introduce 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
    [main.c]
2019-03-24 Remove delay() in page_light(), it doesn't seem to help with the display bug. Fix light value sent. Correct timer2 frequency in comment.
    [main.c]
2019-07-29 Add schematic for the remote control receiver; based on RF solution ZPT-8RS receiver (transmitter is a fobber 8T8).
    [remote-control.kicad_pcb, remote-control.sch]
2019-07-29 Factor out code switching the autopilot to standby. This makes sure that command_target_heading is always initialized.
2019-07-29 Add small program listening for MOB messages on the can bus. It will call the script specified on command line.
2020-03-12 Add diplay cover design
    [wm0_cover.scad]
2020-03-13 Adujst height of strait part to reality
    [wm0_cover.scad]
2020-03-13 Adjust sizes after first print
    [wm0_cover.scad]
2020-03-28 factor out backlight handling allow inverted (white on black) display
    [main.c]
2020-03-28 Better contrast for reverse display Handle reverse in resetdisplay() too.
    [main.c]
2020-04-05 If autopilot is on, allow to switch to standby from more pages - especially error pages.
    [main.c]
2020-04-26 When a route is started or waypoint changes, switch to nav display (and beep)
2020-06-04 Try to dynamically detect rudder min/max limits. compile tested only.
2020-06-16 Fix offset so that we have a back wall.
    [wm0_cover.scad]
2022-07-21 Add a #define for motor overcurrent limit, and make it unsigned
2022-12-01 Convert to kicad 6.x
    [capteur.kicad_pcb, capteur.kicad_sch, clk-capteur.kicad_pcb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]
2025-03-24 Design 3d-printed button for command's encoder
    [bouton-3mm.dxf, bouton-3mm.scad, bouton-3mm.stl]
